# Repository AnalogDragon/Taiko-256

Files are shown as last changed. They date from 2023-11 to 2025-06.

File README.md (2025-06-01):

# Taiko-256  
Taiko JVS for Namco System 256 (246)  

Previously, running Taiko on Namco System 256 required many accessories, such as a JVS (MINI-JV PCB), a SIF PCB, and an intermediate FUTA PCB, making the setup overly complex.  
This project's PCB can fully replace the three boards mentioned above. It features two independent Taiko interfaces, an onboard Service button, and supports direct power supply via ATX.  
Alternatively, this PCB can also be used to replace only the SIF PCB and FUTA PCB while still using the original MINI-JV PCB. However, this does not provide a better experience.  

## PCB:  

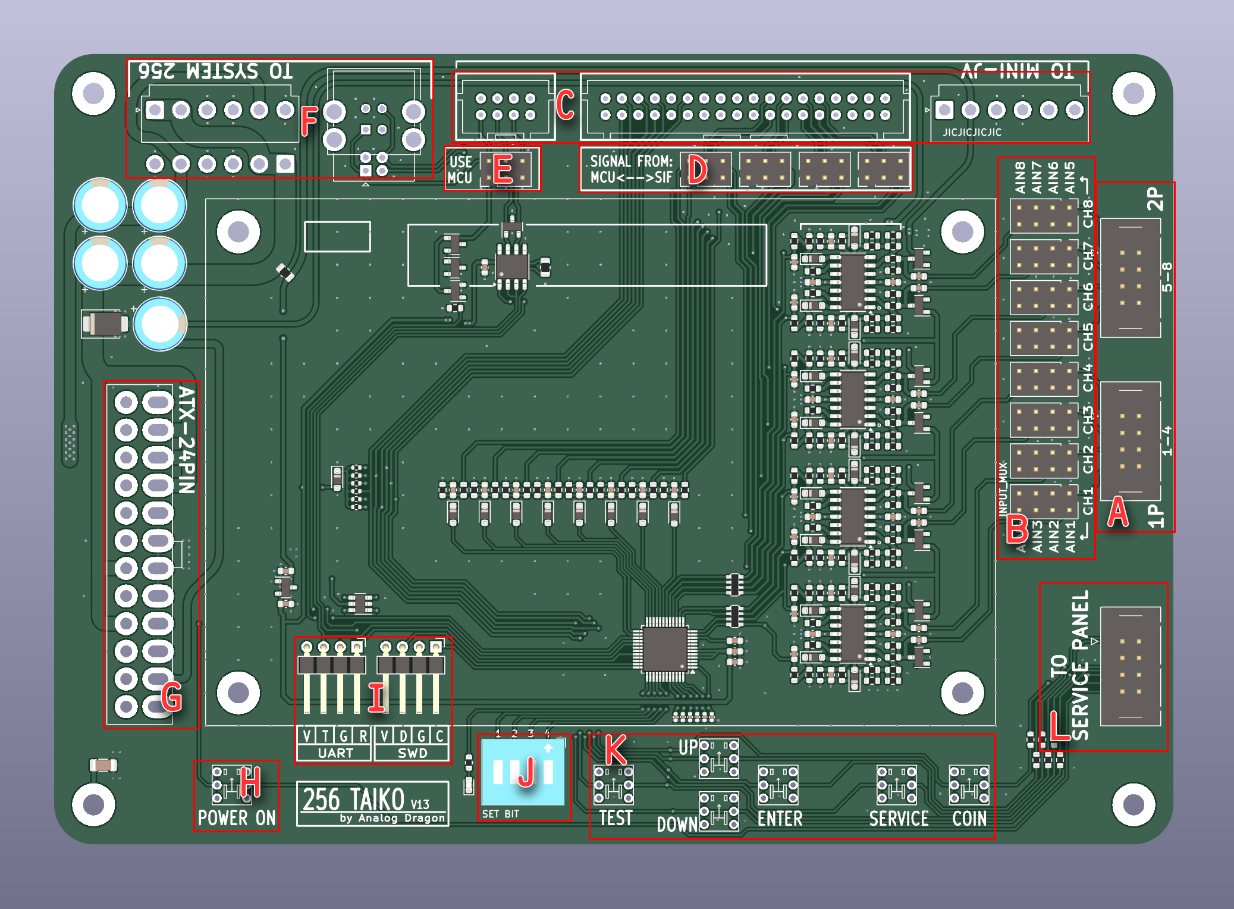
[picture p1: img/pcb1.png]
PCB
  

**Labels in the image:**  
- **A**: Taiko sensor interface. Channels 1\~4 are for Player 1, and channels 5\~8 are for Player 2. Requires connection to a Taiko with vibration sensors (the pins near the board edge are for grounding).  
- **B**: Taiko sensor input swap matrix. Jumpers can be placed in different positions to map inputs to any channel.  
- **C**: Interface for connecting to MINI-JV (can be left unconnected).  
- **D**: When connecting to MINI-JV, determines whether drum signals come from the MCU or SIF (can be left unconnected).  
- **E**: Requires three jumpers to be vertically shorted. If MINI-JV is connected, remove all three jumpers.  
- **F**: Interface for connecting to System 256. Either vertical or right-angle connectors can be soldered (ensure correct placement). For data communication, a USB-A to USB-B cable is required. For System 256 power, a VH3.96-6Pin double-ended reverse cable is needed.  
- **G**: ATX power connector. Either vertical or right-angle connectors can be soldered.  
- **H**: Power switch (requires a latching switch). Press to activate the ATX power supply.  
- **I**: Used for debug.  
- **J**: Configuration code (from left to right, digits 1~4):  
  - **1**: Debug switch (set to OFF during use).  
  - **2**: Frequency limiter switch (set to ON during use, as the System cannot handle overly fast inputs).  
  - **3**: Automatic DON allocation (if the left DON is hit multiple times, System 256 may fail to recognize excessive inputs. Allocating it to the right channel improves the experience. Recommended: ON).  
  - **4**: JVS function (set to ON. Set to OFF if connecting to MINI-JV).  
- **K**: Service function buttons. TEST requires a latching switch, while the others require momentary switches.  
- **L**: Connector for linking to a Service control panel. If the Service buttons need to be extended to another panel, this connector can be used.  

### PCB Image:  
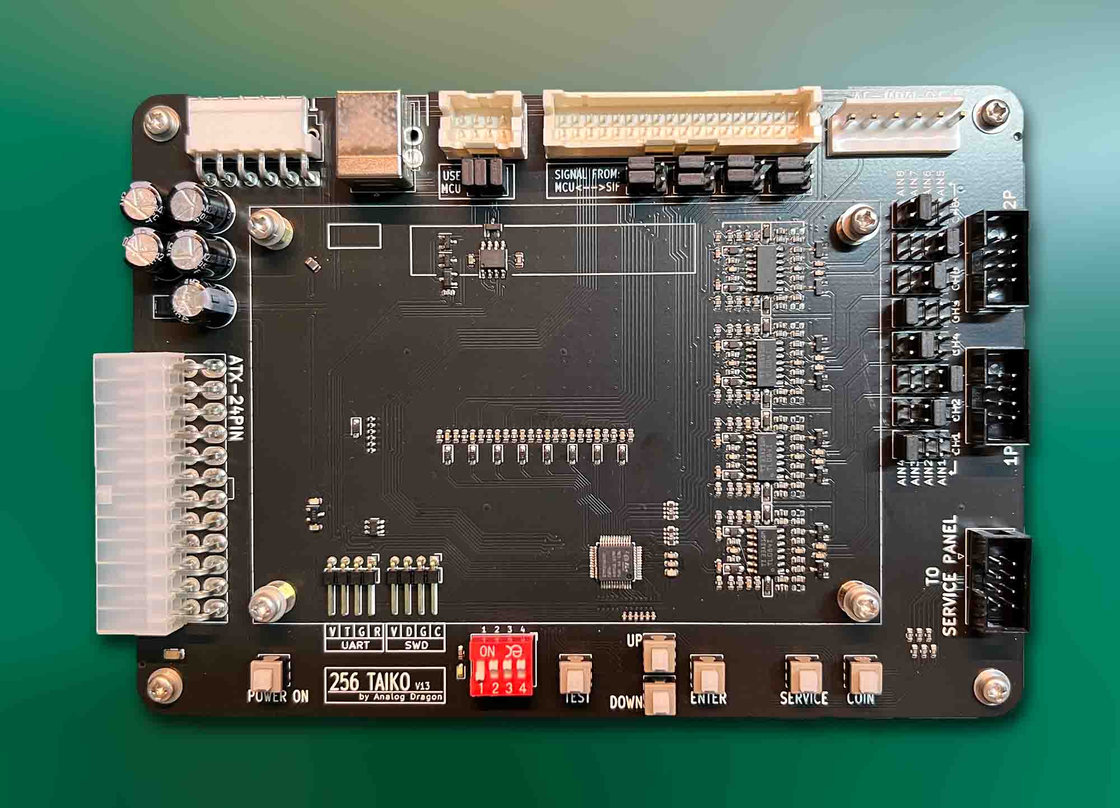
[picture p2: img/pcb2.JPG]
PCB-Photo
  
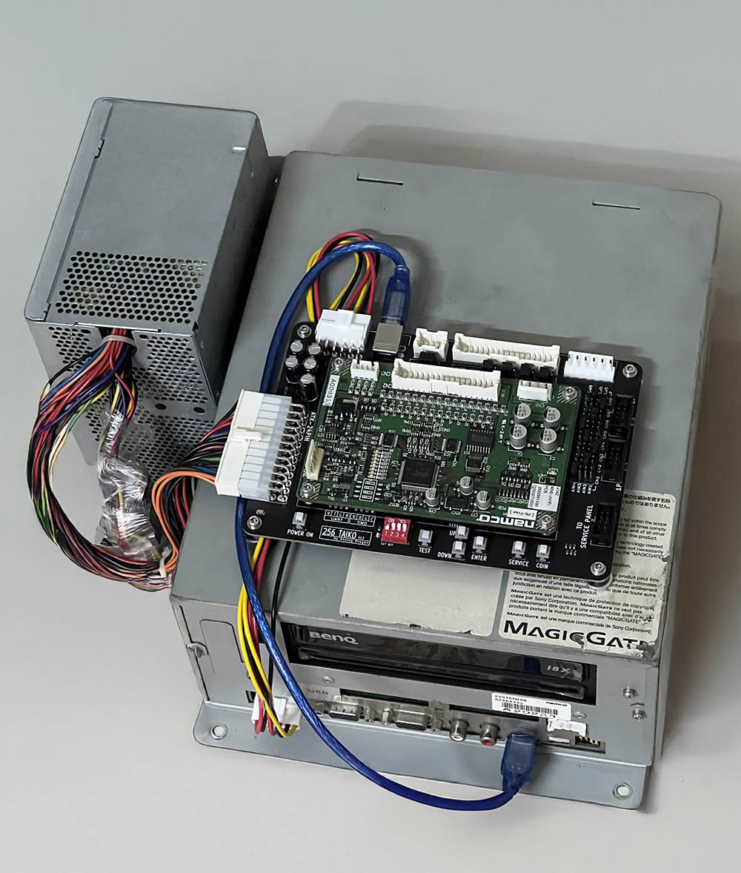
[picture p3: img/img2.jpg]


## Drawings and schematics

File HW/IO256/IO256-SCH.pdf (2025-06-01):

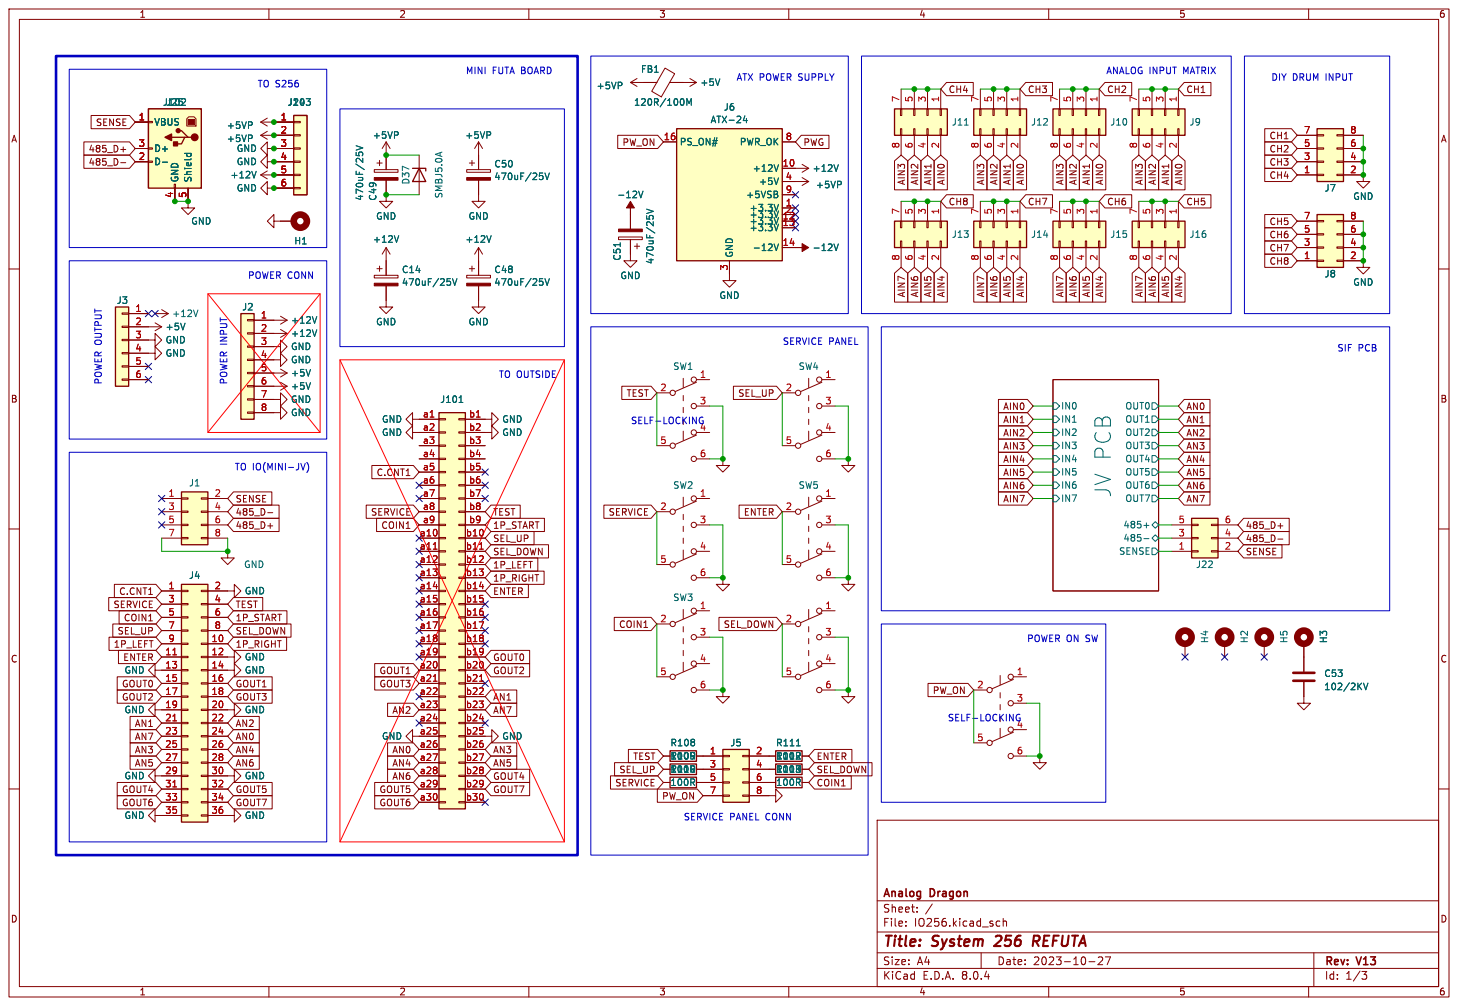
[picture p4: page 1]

ATX POWER SUPPLY POWER OUTPUT

Id: 1/3 Title: System 256 REFUTA

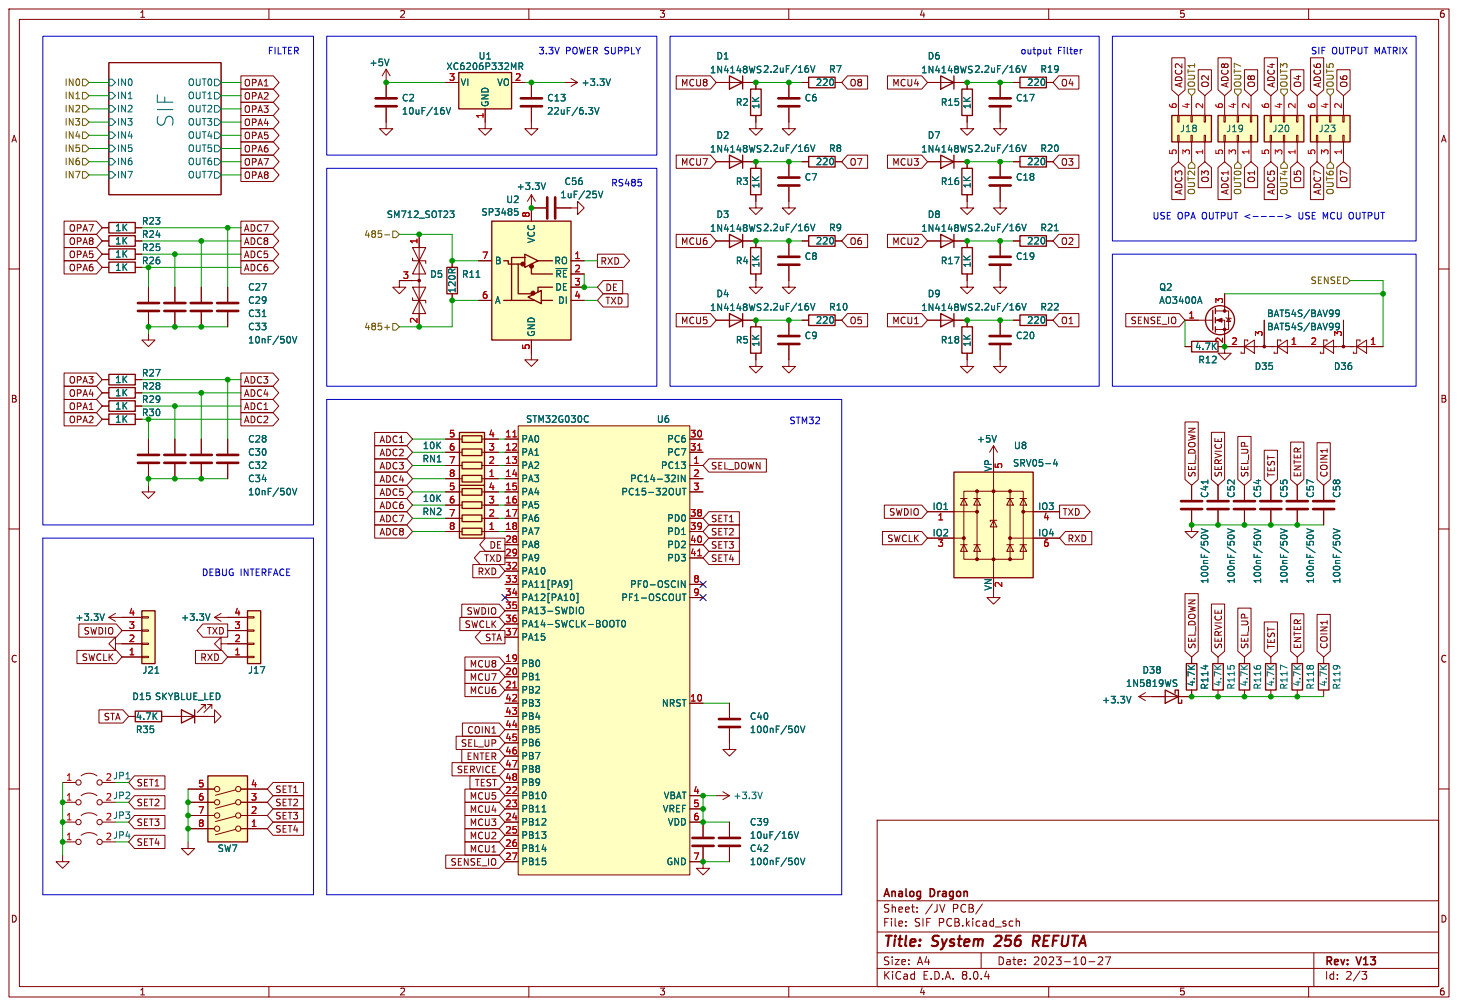
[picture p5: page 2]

Id: 2/3 Title: System 256 REFUTA

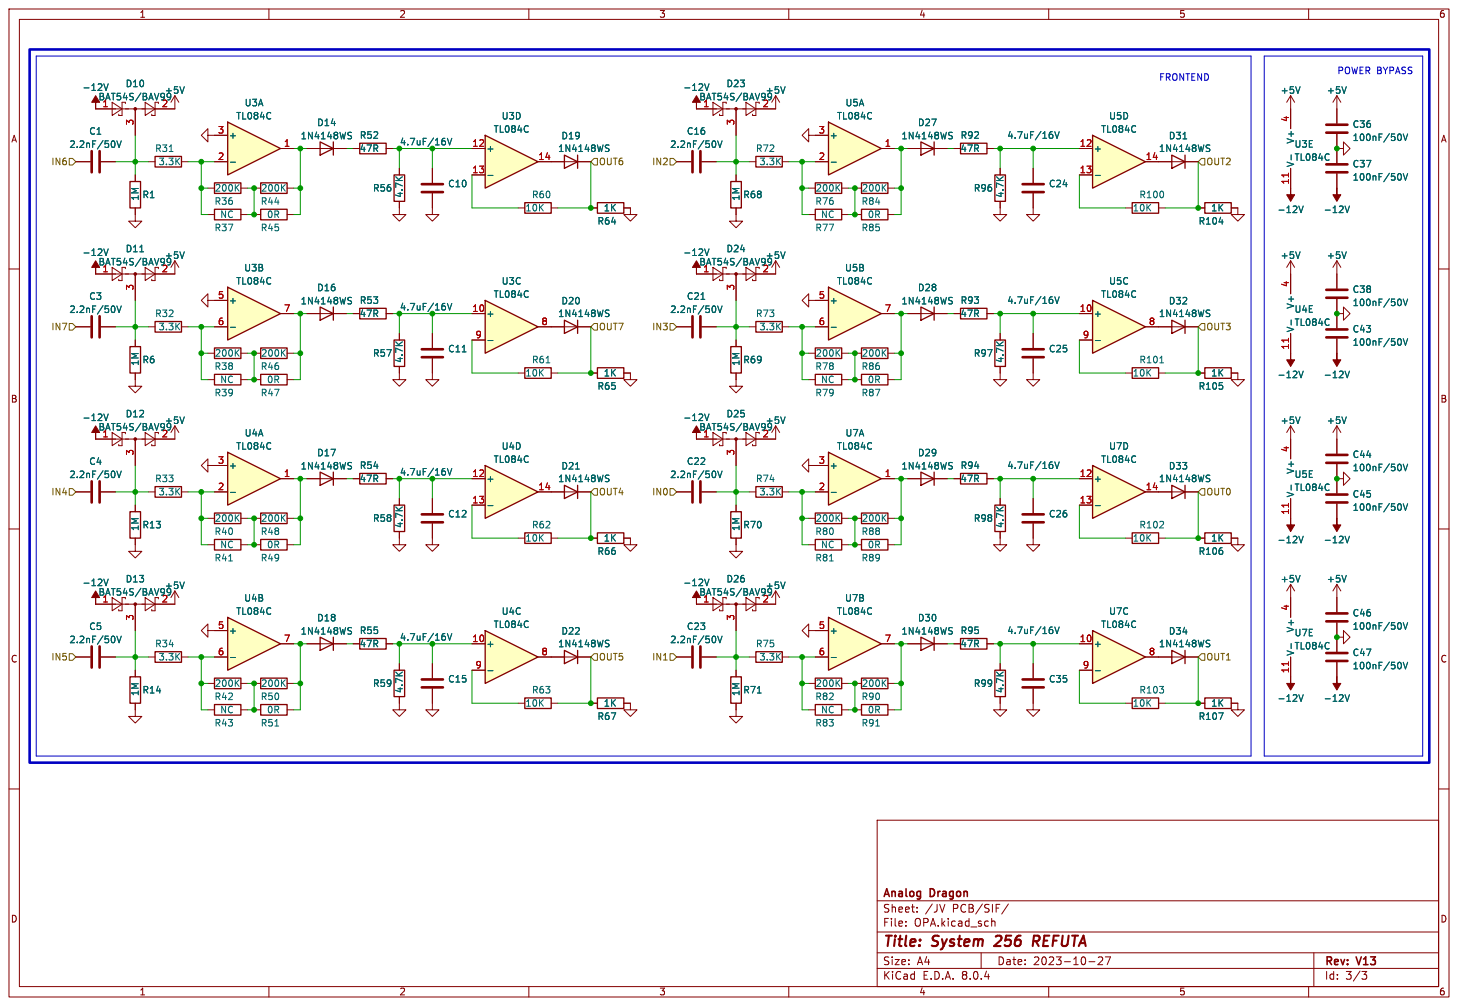
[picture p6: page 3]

Id: 3/3 Title: System 256 REFUTA

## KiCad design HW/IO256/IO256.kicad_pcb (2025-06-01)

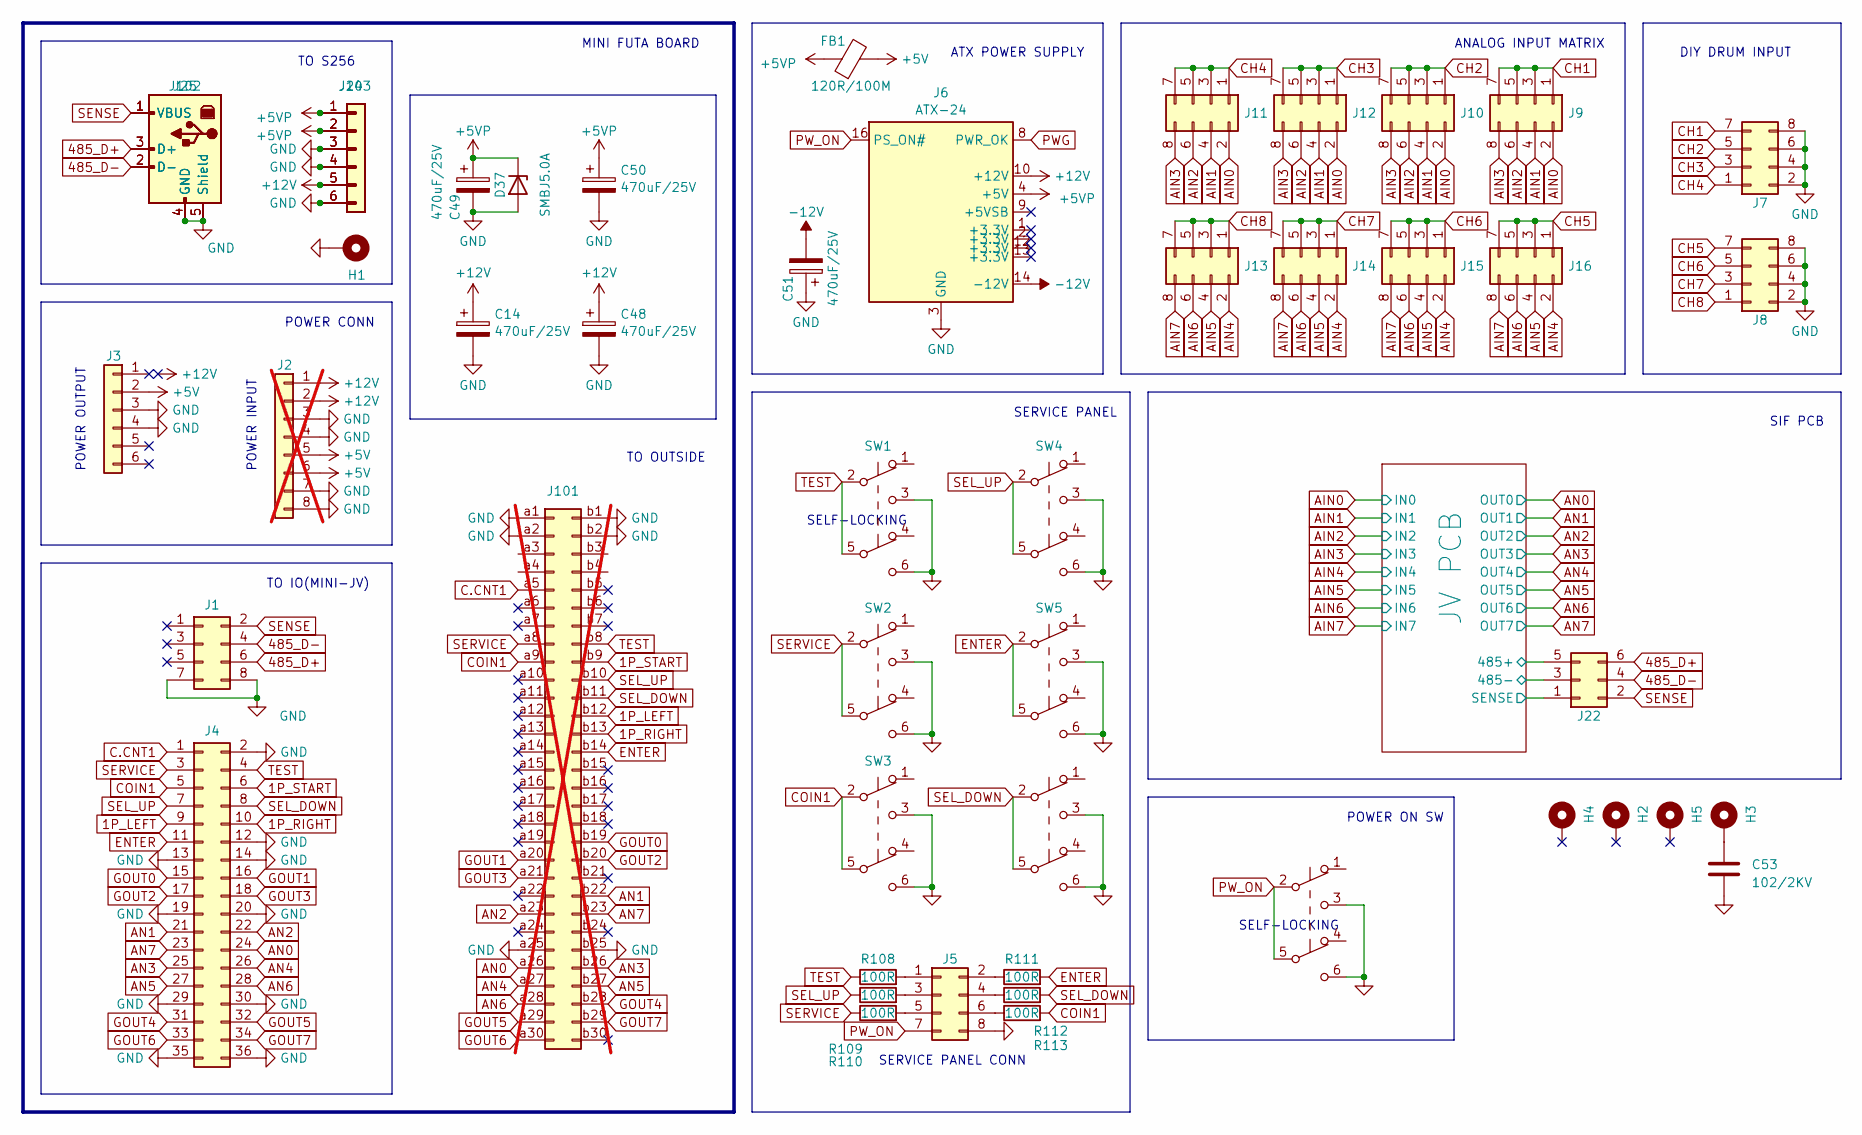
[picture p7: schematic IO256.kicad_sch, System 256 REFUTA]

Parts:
C14, C48, C49, C50, C51: 470uF/25V; CP_Radial_D8.0mm_P3.50mm
C53: 102/2KV; C_1206_3216Metric
D37: SMBJ5.0A; D_SMB
FB1: 120R/100M; R_0805_2012Metric
H1, H2, H3, H4, H5: MINI-JV; MountingHole_3.2mm_M3_DIN965_Pad
J1: Conn_02x04_Odd_Even; B08B-XADSS-N-A
J2: Conn_01x08; JST_VH_B8P-VH-B_1x08_P3.96mm_Vertical; not fitted
J3, J103: Conn_01x06; JST_VH_B6P-VH_1x06_P3.96mm_Vertical
J4: Conn_02x18_Odd_Even; B36B-XADSS-N-A
J5, J7, J8: Conn_02x04_Counter_Clockwise; IDC-Header_2x04_P2.54mm_Vertical
J6: ATX-24; 5557-2x12
J9, J10, J11, J12, J13, J14, J15, J16: Conn_02x04_Counter_Clockwise; PinHeader_2x04_P2.54mm_Vertical
J22: Conn_02x02_Odd_Even; PinHeader_2x03_P2.54mm_Vertical
J24: Conn_01x06; JST_VH_B6PS-VH_1x06_P3.96mm_Horizontal
J25: USB_B; USB_B_OST_USB-B1HSxx_Horizontal
J101: Conn_02x30_Row_Letter_First; IDC-Header_2x30_P2.54mm_Latch6.5mm_Vertical; not fitted
J102: USB_B; USB_B_TE_5787834_Vertical
R108, R109, R110, R111, R112, R113: 100R; R_0603_1608Metric
SW1, SW8: SW6*6_selflock; switch_6x6
SW2, SW3, SW4, SW5, SW6: SW6*6_button; switch_6x6

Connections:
1P_LEFT: J4.9, J101.b12
1P_RIGHT: J4.10, J101.b13
1P_START: J4.6, J101.b9
485_D+: J1.6, J22.6, J25.3 (D+), J102.3 (D+)
485_D-: J1.4, J22.4, J25.2 (D-), J102.2 (D-)
+5V: FB1.2, J2.5, J2.6, J3.2; also elsewhere on the board
+5VP: C49.1, C50.1, D37.1 (K), FB1.1, J6.4 (+5V), J6.6 (+5V), J6.21 (+5V), J6.22 (+5V), J6.23 (+5V), J24.1, J24.2, J103.1, J103.2
+12V: C14.1, C48.1, J2.1, J2.2, J6.10 (+12V), J6.11 (+12V), J24.5, J103.5
-12V: C51.2, J6.14 (-12V); also elsewhere on the board
/JV PCB/485+: J22.5; also elsewhere on the board
/JV PCB/485-: J22.3; also elsewhere on the board
/JV PCB/SENSE: J22.1; also elsewhere on the board
AIN0: J9.2, J10.2, J11.2, J12.2; also elsewhere on the board
AIN1: J9.4, J10.4, J11.4, J12.4; also elsewhere on the board
AIN2: J9.6, J10.6, J11.6, J12.6; also elsewhere on the board
AIN3: J9.8, J10.8, J11.8, J12.8; also elsewhere on the board
AIN4: J13.2, J14.2, J15.2, J16.2; also elsewhere on the board
AIN5: J13.4, J14.4, J15.4, J16.4; also elsewhere on the board
AIN6: J13.6, J14.6, J15.6, J16.6; also elsewhere on the board
AIN7: J13.8, J14.8, J15.8, J16.8; also elsewhere on the board
AN0: J4.24, J101.a26; also elsewhere on the board
AN1: J4.21, J101.b22; also elsewhere on the board
AN2: J4.22, J101.a23; also elsewhere on the board
AN3: J4.25, J101.b26; also elsewhere on the board
AN4: J4.26, J101.a27; also elsewhere on the board
AN5: J4.27, J101.b27; also elsewhere on the board
AN6: J4.28, J101.a28; also elsewhere on the board
AN7: J4.23, J101.b23; also elsewhere on the board
C.CNT1: J4.1, J101.a5
CH1: J7.7, J9.1, J9.3, J9.5, J9.7
CH2: J7.5, J10.1, J10.3, J10.5, J10.7
CH3: J7.3, J12.1, J12.3, J12.5, J12.7
CH4: J7.1, J11.1, J11.3, J11.5, J11.7
CH5: J8.7, J16.1, J16.3, J16.5, J16.7
CH6: J8.5, J15.1, J15.3, J15.5, J15.7
CH7: J8.3, J14.1, J14.3, J14.5, J14.7
CH8: J8.1, J13.1, J13.3, J13.5, J13.7
COIN1: J4.5, R113.2, SW3.2 (B), SW3.5 (B); also elsewhere on the board
ENTER: J4.11, R111.2, SW5.2 (B), SW5.5 (B); also elsewhere on the board
GND: C14.2, C48.2, C49.2, C50.2, C51.1, C53.2, D37.2 (A), H1.1, J1.7, J1.8, J2.3, J2.4, J2.7, J2.8, J3.3, J3.4, J4.2, J4.12, J4.13, J4.14, J4.19, J4.20, J4.29, J4.30, J4.35, J4.36, J5.8, J6.3 (GND), J6.5 (GND), J6.7 (GND), J6.15 (GND), J6.17 (GND), J6.18 (GND), J6.19 (GND), J6.24 (GND), J7.2, J7.4, J7.6, J7.8, J8.2, J8.4, J8.6, J8.8, J24.3, J24.4, J24.6, J25.4 (GND), J25.5 (Shield), J101.a1, J101.a2, J101.a25, J101.b1, J101.b2, J101.b25, J102.4 (GND), J102.5 (Shield), J103.3, J103.4, J103.6, SW1.3 (C), SW1.6 (C), SW2.3 (C), SW2.6 (C), SW3.3 (C), SW3.6 (C), SW4.3 (C), SW4.6 (C), SW5.3 (C), SW5.6 (C), SW6.3 (C), SW6.6 (C), SW8.3 (C), SW8.6 (C); also elsewhere on the board
GOUT0: J4.15, J101.b19
GOUT1: J4.16, J101.a20
GOUT2: J4.17, J101.b20
GOUT3: J4.18, J101.a21
GOUT4: J4.31, J101.b28
GOUT5: J4.32, J101.a29
GOUT6: J4.33, J101.a30
GOUT7: J4.34, J101.b29
unnamed: C53.1, H3.1
unnamed: J5.1, R108.2
unnamed: J5.2, R111.1
unnamed: J5.3, R109.2
unnamed: J5.4, R112.1
unnamed: J5.5, R110.2
unnamed: J5.6, R113.1
PWG: J6.8 (PWR_OK)
PW_ON: J5.7, J6.16 (PS_ON#), SW8.2 (B), SW8.5 (B)
SEL_DOWN: J4.8, R112.2, SW6.2 (B), SW6.5 (B); also elsewhere on the board
SEL_UP: J4.7, R109.1, SW4.2 (B), SW4.5 (B); also elsewhere on the board
SENSE: J1.2, J22.2, J25.1 (VBUS), J102.1 (VBUS)
SERVICE: J4.3, R110.1, SW2.2 (B), SW2.5 (B); also elsewhere on the board
TEST: J4.4, R108.1, SW1.2 (B), SW1.5 (B); also elsewhere on the board

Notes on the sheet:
SERVICE PANEL CONN
DIY DRUM INPUT
SERVICE PANEL
ANALOG INPUT MATRIX
SELF-LOCKING
TO S256
SIF PCB
MINI FUTA BOARD
POWER OUTPUT
TO OUTSIDE
TO IO(MINI-JV)
POWER CONN
ATX POWER SUPPLY
POWER INPUT
POWER ON SW

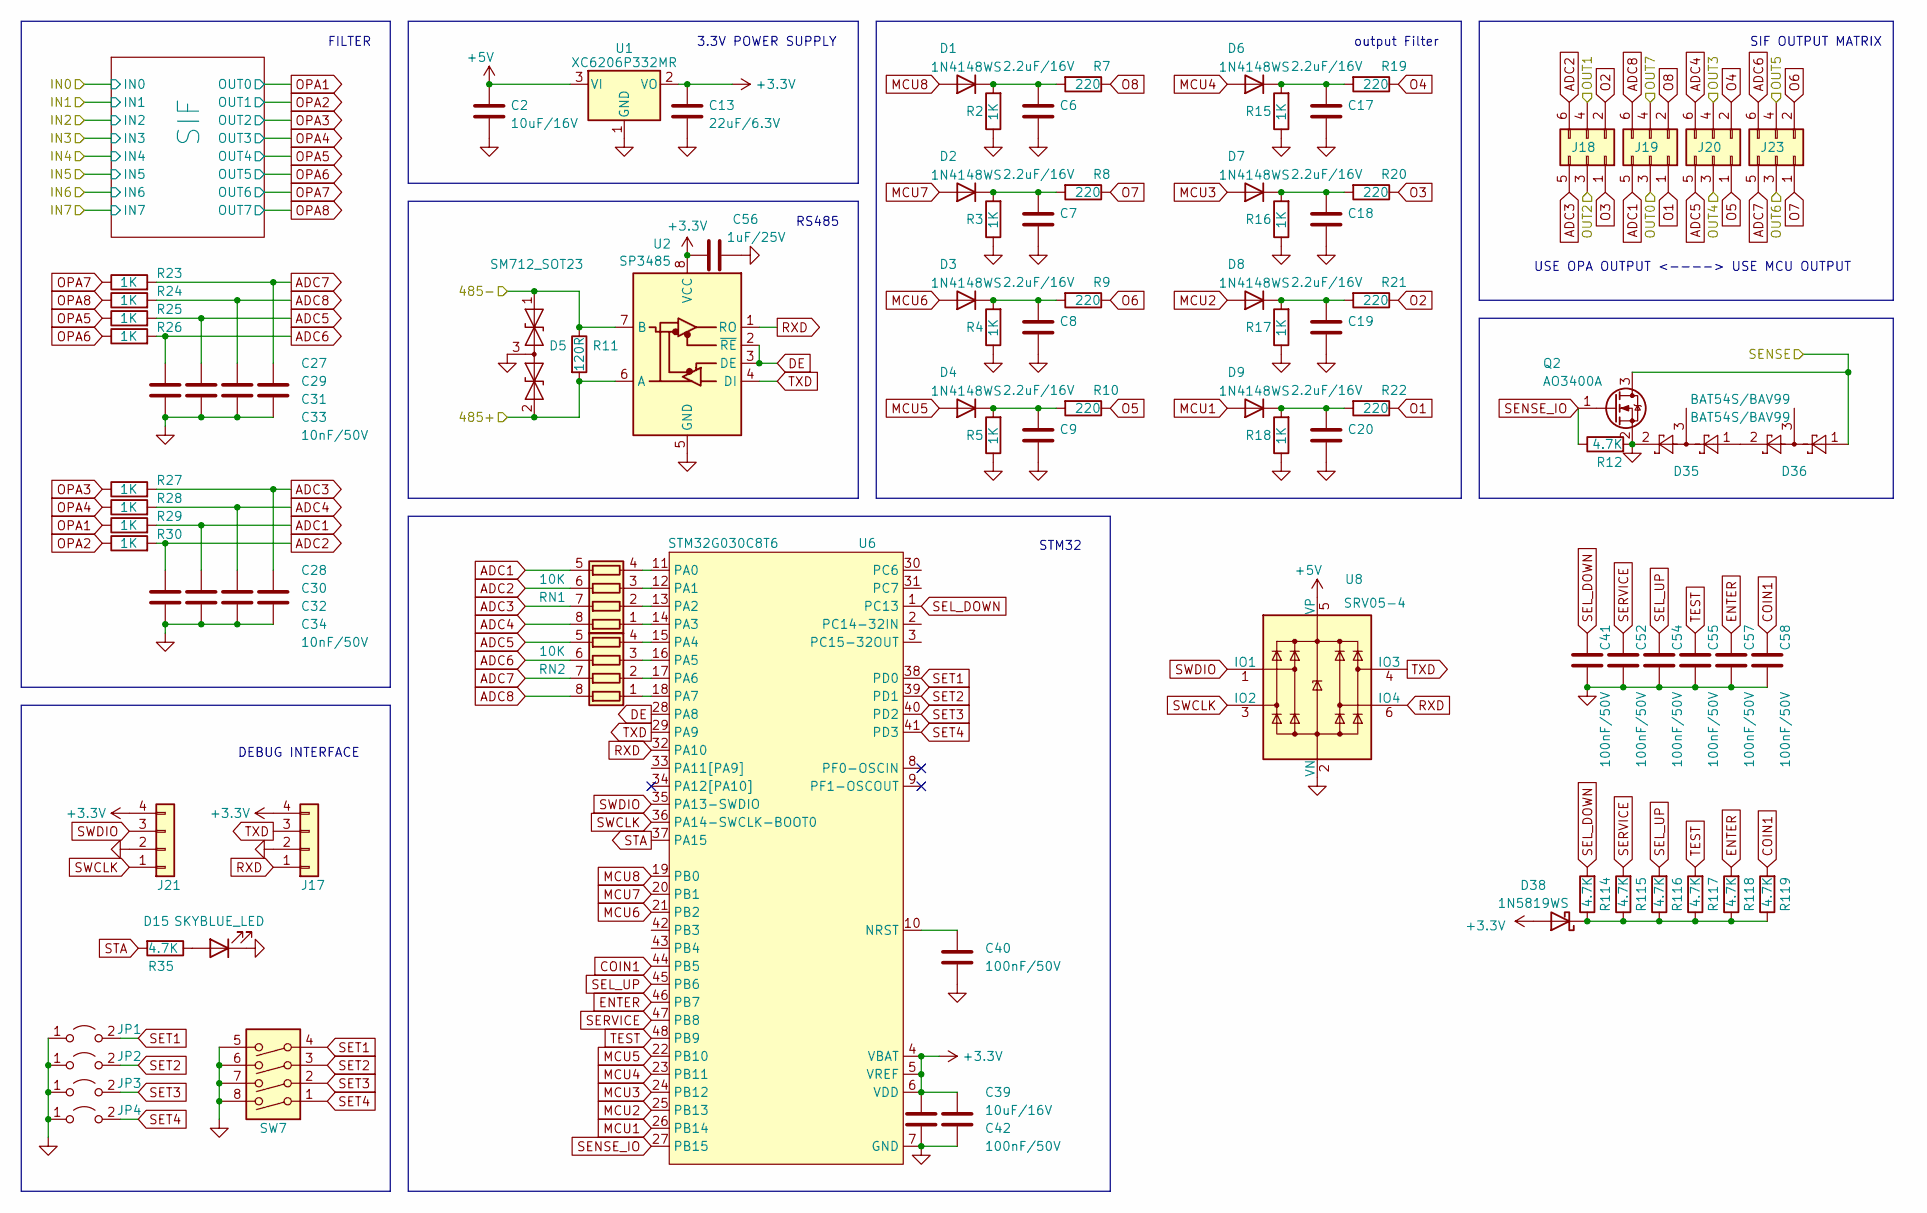
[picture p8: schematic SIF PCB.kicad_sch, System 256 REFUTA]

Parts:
C2, C39: 10uF/16V; C_0603_1608Metric
C6, C7, C8, C9, C17, C18, C19, C20: 2.2uF/16V; C_0603_1608Metric
C13: 22uF/6.3V; C_0603_1608Metric
C27, C28, C29, C30, C31, C32, C33, C34: 10nF/50V; C_0603_1608Metric
C40, C42: 100nF/50V; C_0603_1608Metric
C41, C52, C54, C55, C57, C58: 100nF/50V; C_0402_1005Metric
C56: 1uF/25V; C_0603_1608Metric
D1, D2, D3, D4, D6, D7, D8, D9: 1N4148WS; D_SOD-323_HandSoldering
D5: SM712_SOT23; SOT-23
D15: SKYBLUE_LED; LED_0603_1608Metric
D35, D36: BAT54S/BAV99; SOT-23
D38: 1N5819WS; D_SOD-323_HandSoldering
J17, J21: Conn_01x04; PinHeader_1x04_P2.54mm_Horizontal
J18, J19, J20, J23: Conn_02x03_Odd_Even; PinHeader_2x03_P2.54mm_Vertical
JP1, JP2, JP3, JP4: Jumper_2_Open; JP_0603
Q2: AO3400A; SOT-23
R2, R3, R4, R5, R15, R16, R17, R18, R23, R24, R25, R26, R27, R28, R29, R30: 1K; R_0603_1608Metric
R7, R8, R9, R10, R19, R20, R21, R22: 220; R_0603_1608Metric
R11: 120R; R_0805_2012Metric
R12, R35: 4.7K; R_0603_1608Metric
R114, R115, R116, R117, R118, R119: 4.7K; R_0402_1005Metric
RN1, RN2: 10K; R_Array_Convex_4x0603
SW7: SW_DIP_x04; SW_DIP_SPSTx04_Slide_9.78x12.34mm_W7.62mm_P2.54mm
U1: XC6206P332MR; SOT-23
U2: SP3485; SOIC-8_3.9x4.9mm_P1.27mm
U6: STM32G030C8T6; LQFP-48_7x7mm_P0.5mm
U8: SRV05-4; SOT-23-6

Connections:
+3.3V: C13.1, C39.1, C42.1, C56.1, D38.2 (A), J17.4, J21.4, U1.2 (VO), U2.8 (VCC), U6.4 (VBAT), U6.5 (VREF), U6.6 (VDD)
+5V: C2.1, U1.3 (VI), U8.5 (VP); also elsewhere on the board
/JV PCB/485+: D5.2 (A2), R11.2, U2.6 (A); also elsewhere on the board
/JV PCB/485-: D5.1 (A1), R11.1, U2.7 (B); also elsewhere on the board
/JV PCB/SENSE: D36.1, Q2.3 (D); also elsewhere on the board
ADC1: C30.1, J19.5, R29.2, RN1.5 (R4.2)
ADC2: C28.1, J18.6, R30.2, RN1.6 (R3.2)
ADC3: C34.1, J18.5, R27.2, RN1.7 (R2.2)
ADC4: C32.1, J20.6, R28.2, RN1.8 (R1.2)
ADC5: C29.1, J20.5, R25.2, RN2.5 (R4.2)
ADC6: C27.1, J23.6, R26.2, RN2.6 (R3.2)
ADC7: C33.1, J23.5, R23.2, RN2.7 (R2.2)
ADC8: C31.1, J19.6, R24.2, RN2.8 (R1.2)
AN0: J19.3; also elsewhere on the board
AN1: J18.4; also elsewhere on the board
AN2: J18.3; also elsewhere on the board
AN3: J20.4; also elsewhere on the board
AN4: J20.3; also elsewhere on the board
AN5: J23.4; also elsewhere on the board
AN6: J23.3; also elsewhere on the board
AN7: J19.4; also elsewhere on the board
COIN1: C58.1, R119.2, U6.44 (PB5); also elsewhere on the board
DE: U2.2 (~RE), U2.3 (DE), U6.28 (PA8)
ENTER: C57.1, R118.2, U6.46 (PB7); also elsewhere on the board
GND: C2.2, C6.1, C7.1, C8.1, C9.1, C13.2, C17.1, C18.1, C19.1, C20.1, C27.2, C28.2, C29.2, C30.2, C31.2, C32.2, C33.2, C34.2, C39.2, C40.2, C41.2, C42.2, C52.2, C54.2, C55.2, C56.2, C57.2, C58.2, D5.3 (common), D15.1 (K), D35.2, J17.2, J21.2, JP1.1 (A), JP2.1 (A), JP3.1 (A), JP4.1 (A), Q2.2 (S), R2.1, R3.1, R4.1, R5.1, R12.2, R15.1, R16.1, R17.1, R18.1, SW7.5, SW7.6, SW7.7, SW7.8, U1.1 (GND), U2.5 (GND), U6.7 (GND), U8.2 (VN); also elsewhere on the board
MCU1: D9.2 (A), U6.26 (PB14)
MCU2: D8.2 (A), U6.25 (PB13)
MCU3: D7.2 (A), U6.24 (PB12)
MCU4: D6.2 (A), U6.23 (PB11)
MCU5: D4.2 (A), U6.22 (PB10)
MCU6: D3.2 (A), U6.21 (PB2)
MCU7: D2.2 (A), U6.20 (PB1)
MCU8: D1.2 (A), U6.19 (PB0)
unnamed: C6.2, D1.1 (K), R2.2, R7.2
unnamed: C7.2, D2.1 (K), R3.2, R8.2
unnamed: C8.2, D3.1 (K), R4.2, R9.2
unnamed: C9.2, D4.1 (K), R5.2, R10.2
unnamed: C17.2, D6.1 (K), R15.2, R19.2
unnamed: C18.2, D7.1 (K), R16.2, R20.2
unnamed: C19.2, D8.1 (K), R17.2, R21.2
unnamed: C20.2, D9.1 (K), R18.2, R22.2
unnamed: D15.2 (A), R35.1
unnamed: D35.1, D36.2
unnamed: D38.1 (K), R114.1, R115.1, R116.1, R117.1, R118.1, R119.1
unnamed: RN1.1 (R1.1), U6.14 (PA3)
unnamed: RN1.2 (R2.1), U6.13 (PA2)
unnamed: RN1.3 (R3.1), U6.12 (PA1)
unnamed: RN1.4 (R4.1), U6.11 (PA0)
unnamed: RN2.1 (R1.1), U6.18 (PA7)
unnamed: RN2.2 (R2.1), U6.17 (PA6)
unnamed: RN2.3 (R3.1), U6.16 (PA5)
unnamed: RN2.4 (R4.1), U6.15 (PA4)
unnamed: C40.1, U6.10 (NRST)
O1: J19.1, R22.1
O2: J18.2, R21.1
O3: J18.1, R20.1
O4: J20.2, R19.1
O5: J20.1, R10.1
O6: J23.2, R9.1
O7: J23.1, R8.1
O8: J19.2, R7.1
OPA1: R29.1; also elsewhere on the board
OPA2: R30.1; also elsewhere on the board
OPA3: R27.1; also elsewhere on the board
OPA4: R28.1; also elsewhere on the board
OPA5: R25.1; also elsewhere on the board
OPA6: R26.1; also elsewhere on the board
OPA7: R23.1; also elsewhere on the board
OPA8: R24.1; also elsewhere on the board
RXD: J17.1, U2.1 (RO), U6.32 (PA10), U8.6 (IO4)
SEL_DOWN: C41.1, R114.2, U6.1 (PC13); also elsewhere on the board
SEL_UP: C54.1, R116.2, U6.45 (PB6); also elsewhere on the board
SENSE_IO: Q2.1 (G), R12.1, U6.27 (PB15)
SERVICE: C52.1, R115.2, U6.47 (PB8); also elsewhere on the board
SET1: JP1.2 (B), SW7.4, U6.38 (PD0)
SET2: JP2.2 (B), SW7.3, U6.39 (PD1)
SET3: JP3.2 (B), SW7.2, U6.40 (PD2)
SET4: JP4.2 (B), SW7.1, U6.41 (PD3)
STA: R35.2, U6.37 (PA15)
SWCLK: J21.1, U6.36 (PA14-SWCLK-BOOT0), U8.3 (IO2)
SWDIO: J21.3, U6.35 (PA13-SWDIO), U8.1 (IO1)
TEST: C55.1, R117.2, U6.48 (PB9); also elsewhere on the board
TXD: J17.3, U2.4 (DI), U6.29 (PA9), U8.4 (IO3)

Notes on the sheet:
SIF OUTPUT MATRIX
DEBUG INTERFACE
STM32
3.3V POWER SUPPLY
RS485
output Filter
USE OPA OUTPUT <----> USE MCU OUTPUT
FILTER

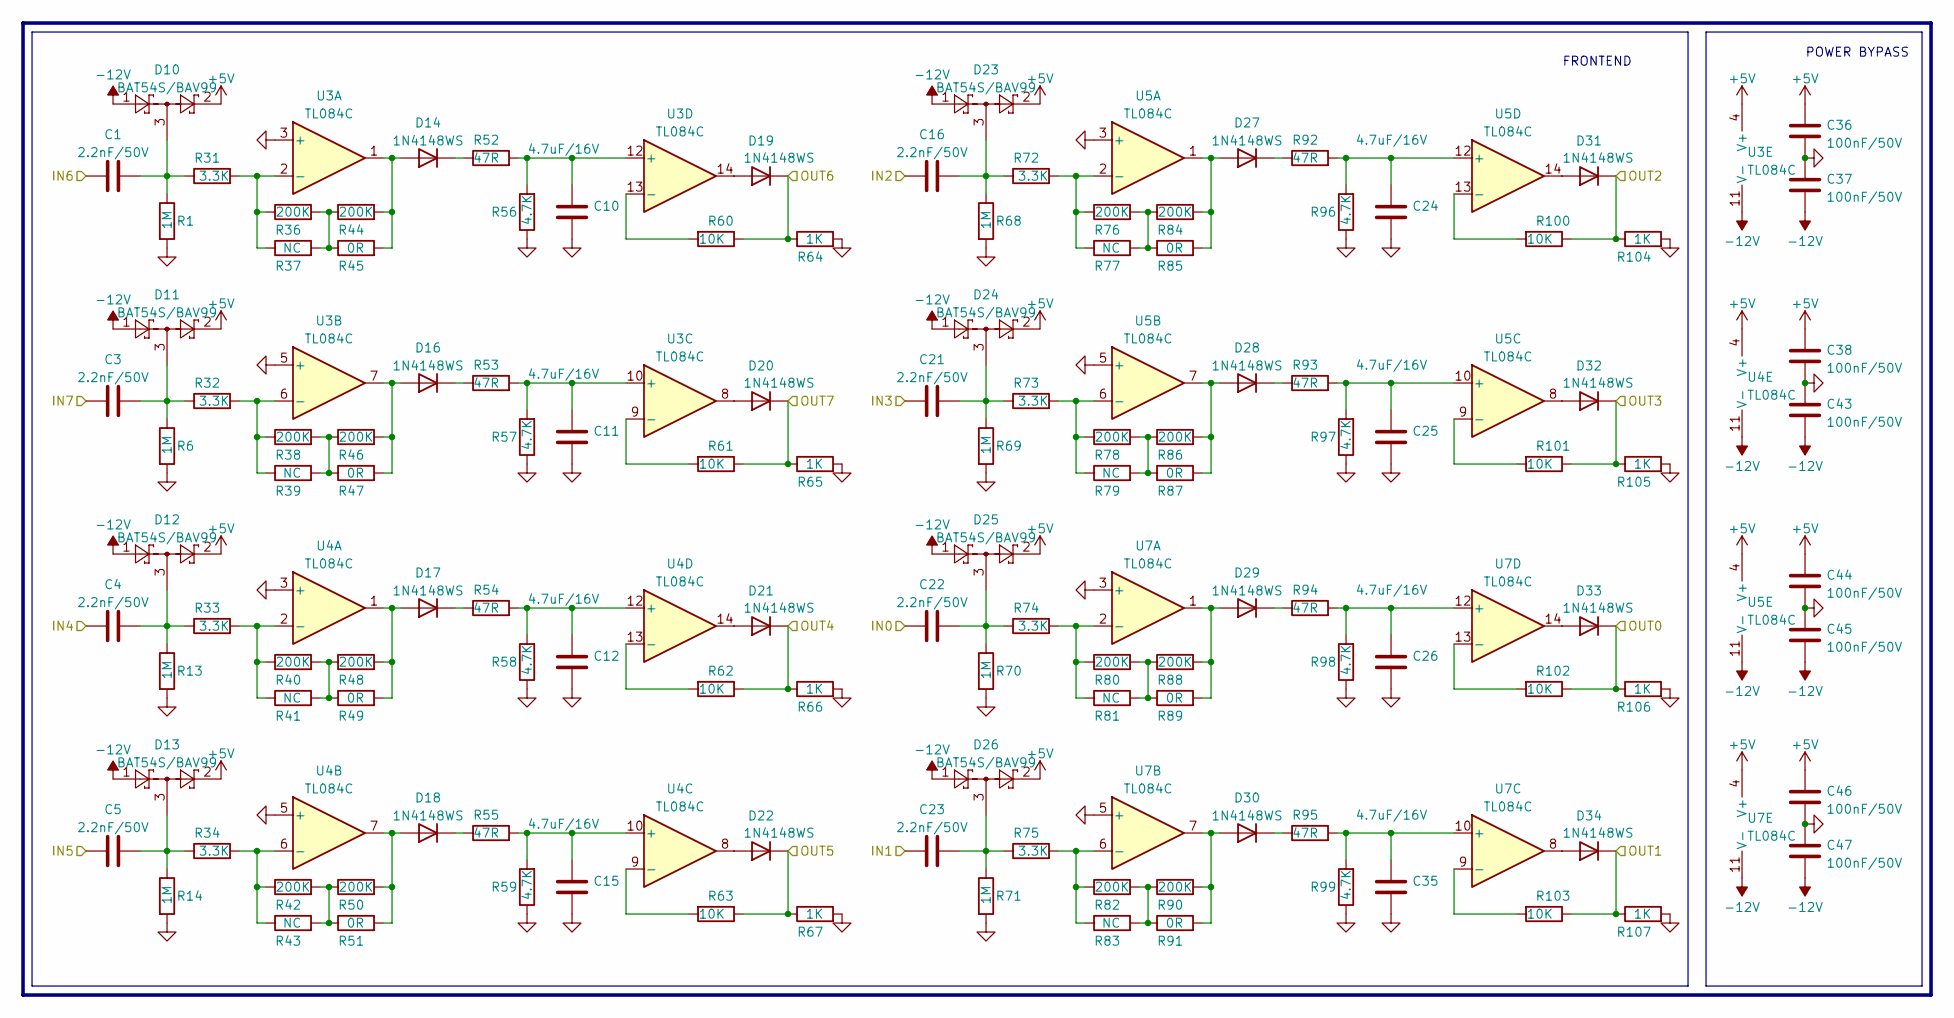
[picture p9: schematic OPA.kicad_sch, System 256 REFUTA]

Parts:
C1, C3, C4, C5, C16, C21, C22, C23: 2.2nF/50V; C_0603_1608Metric
C10, C11, C12, C15, C24, C25, C26, C35: 4.7uF/16V; C_0603_1608Metric
C36, C37, C38, C43, C44, C45, C46, C47: 100nF/50V; C_0603_1608Metric
D10, D11, D12, D13, D23, D24, D25, D26: BAT54S/BAV99; SOT-23
D14, D16, D17, D18, D19, D20, D21, D22, D27, D28, D29, D30, D31, D32, D33, D34: 1N4148WS; D_SOD-323_HandSoldering
R1, R6, R13, R14, R68, R69, R70, R71: 1M; R_0603_1608Metric
R31, R32, R33, R34, R72, R73, R74, R75: 3.3K; R_0603_1608Metric
R36, R38, R40, R42, R44, R46, R48, R50, R76, R78, R80, R82, R84, R86, R88, R90: 200K; R_0603_1608Metric
R37, R39, R41, R43, R77, R79, R81, R83: NC; R_0603_1608Metric
R45, R47, R49, R51, R85, R87, R89, R91: 0R; R_0603_1608Metric
R52, R53, R54, R55, R92, R93, R94, R95: 47R; R_0603_1608Metric
R56, R57, R58, R59, R96, R97, R98, R99: 4.7K; R_0603_1608Metric
R60, R61, R62, R63, R100, R101, R102, R103: 10K; R_0603_1608Metric
R64, R65, R66, R67, R104, R105, R106, R107: 1K; R_0603_1608Metric
U3, U4, U5, U7: TL084C; SO-14_3.9x8.65mm_P1.27mm

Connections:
+5V: C36.2, C38.2, C44.2, C46.2, D10.2, D11.2, D12.2, D13.2, D23.2, D24.2, D25.2, D26.2, U3.4 (V+), U4.4 (V+), U5.4 (V+), U7.4 (V+); also elsewhere on the board
-12V: C37.1, C43.1, C45.1, C47.1, D10.1, D11.1, D12.1, D13.1, D23.1, D24.1, D25.1, D26.1, U3.11 (V-), U4.11 (V-), U5.11 (V-), U7.11 (V-); also elsewhere on the board
AIN0: C22.1; also elsewhere on the board
AIN1: C23.1; also elsewhere on the board
AIN2: C16.1; also elsewhere on the board
AIN3: C21.1; also elsewhere on the board
AIN4: C4.1; also elsewhere on the board
AIN5: C5.1; also elsewhere on the board
AIN6: C1.1; also elsewhere on the board
AIN7: C3.1; also elsewhere on the board
GND: C10.1, C11.1, C12.1, C15.1, C24.1, C25.1, C26.1, C35.1, C36.1, C37.2, C38.1, C43.2, C44.1, C45.2, C46.1, C47.2, R1.2, R6.2, R13.2, R14.2, R56.1, R57.1, R58.1, R59.1, R64.2, R65.2, R66.2, R67.2, R68.2, R69.2, R70.2, R71.2, R96.1, R97.1, R98.1, R99.1, R104.2, R105.2, R106.2, R107.2, U3.3 (+), U3.5 (+), U4.3 (+), U4.5 (+), U5.3 (+), U5.5 (+), U7.3 (+), U7.5 (+); also elsewhere on the board
unnamed: C1.2, D10.3, R1.1, R31.1
unnamed: C3.2, D11.3, R6.1, R32.1
unnamed: C4.2, D12.3, R13.1, R33.1
unnamed: C5.2, D13.3, R14.1, R34.1
unnamed: C16.2, D23.3, R68.1, R72.1
unnamed: C21.2, D24.3, R69.1, R73.1
unnamed: C22.2, D25.3, R70.1, R74.1
unnamed: C23.2, D26.3, R71.1, R75.1
unnamed: D14.2 (A), R44.2, R45.2, U3.1
unnamed: D14.1 (K), R52.1
unnamed: D16.2 (A), R46.2, R47.2, U3.7
unnamed: D16.1 (K), R53.1
unnamed: D17.2 (A), R48.2, R49.2, U4.1
unnamed: D17.1 (K), R54.1
unnamed: D18.2 (A), R50.2, R51.2, U4.7
unnamed: D18.1 (K), R55.1
unnamed: D19.2 (A), U3.14
unnamed: D20.2 (A), U3.8
unnamed: D21.2 (A), U4.14
unnamed: D22.2 (A), U4.8
unnamed: D27.2 (A), R84.2, R85.2, U5.1
unnamed: D27.1 (K), R92.1
unnamed: D28.2 (A), R86.2, R87.2, U5.7
unnamed: D28.1 (K), R93.1
unnamed: D29.2 (A), R88.2, R89.2, U7.1
unnamed: D29.1 (K), R94.1
unnamed: D30.2 (A), R90.2, R91.2, U7.7
unnamed: D30.1 (K), R95.1
unnamed: D31.2 (A), U5.14
unnamed: D32.2 (A), U5.8
unnamed: D33.2 (A), U7.14
unnamed: D34.2 (A), U7.8
unnamed: R36.2, R37.2, R44.1, R45.1
unnamed: R38.2, R39.2, R46.1, R47.1
unnamed: R40.2, R41.2, R48.1, R49.1
unnamed: R42.2, R43.2, R50.1, R51.1
unnamed: R76.2, R77.2, R84.1, R85.1
unnamed: R78.2, R79.2, R86.1, R87.1
unnamed: R80.2, R81.2, R88.1, R89.1
unnamed: R82.2, R83.2, R90.1, R91.1
unnamed: R31.2, R36.1, R37.1, U3.2 (-)
unnamed: R32.2, R38.1, R39.1, U3.6 (-)
unnamed: C11.2, R53.2, R57.2, U3.10 (+)
unnamed: R61.2, U3.9 (-)
unnamed: C10.2, R52.2, R56.2, U3.12 (+)
unnamed: R60.2, U3.13 (-)
unnamed: R33.2, R40.1, R41.1, U4.2 (-)
unnamed: R34.2, R42.1, R43.1, U4.6 (-)
unnamed: C15.2, R55.2, R59.2, U4.10 (+)
unnamed: R63.2, U4.9 (-)
unnamed: C12.2, R54.2, R58.2, U4.12 (+)
unnamed: R62.2, U4.13 (-)
unnamed: R72.2, R76.1, R77.1, U5.2 (-)
unnamed: R73.2, R78.1, R79.1, U5.6 (-)
unnamed: C25.2, R93.2, R97.2, U5.10 (+)
unnamed: R101.2, U5.9 (-)
unnamed: C24.2, R92.2, R96.2, U5.12 (+)
unnamed: R100.2, U5.13 (-)
unnamed: R74.2, R80.1, R81.1, U7.2 (-)
unnamed: R75.2, R82.1, R83.1, U7.6 (-)
unnamed: C35.2, R95.2, R99.2, U7.10 (+)
unnamed: R103.2, U7.9 (-)
unnamed: C26.2, R94.2, R98.2, U7.12 (+)
unnamed: R102.2, U7.13 (-)
OPA1: D33.1 (K), R102.1, R106.1; also elsewhere on the board
OPA2: D34.1 (K), R103.1, R107.1; also elsewhere on the board
OPA3: D31.1 (K), R100.1, R104.1; also elsewhere on the board
OPA4: D32.1 (K), R101.1, R105.1; also elsewhere on the board
OPA5: D21.1 (K), R62.1, R66.1; also elsewhere on the board
OPA6: D22.1 (K), R63.1, R67.1; also elsewhere on the board
OPA7: D19.1 (K), R60.1, R64.1; also elsewhere on the board
OPA8: D20.1 (K), R61.1, R65.1; also elsewhere on the board

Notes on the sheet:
POWER BYPASS
FRONTEND

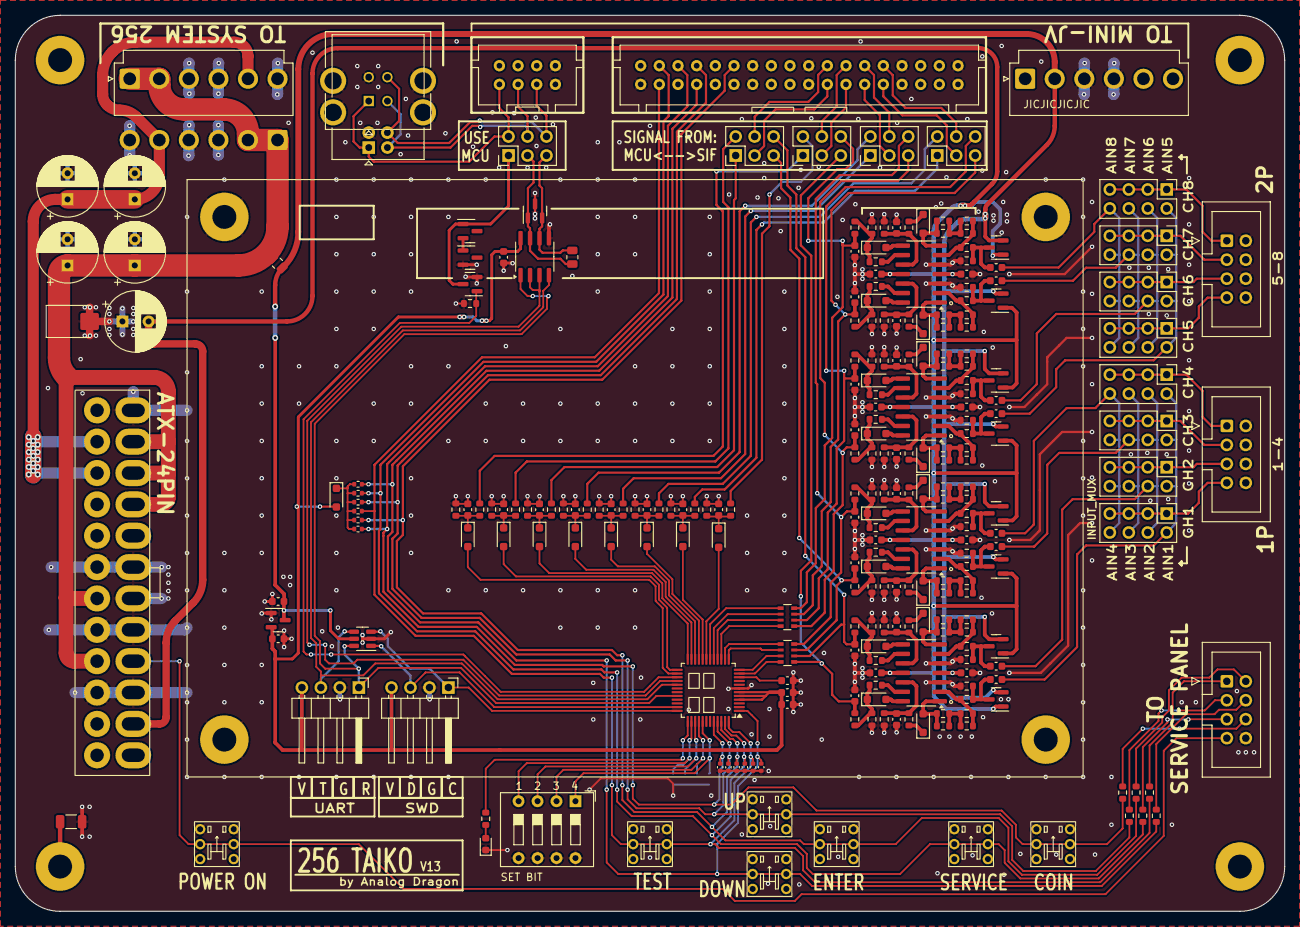
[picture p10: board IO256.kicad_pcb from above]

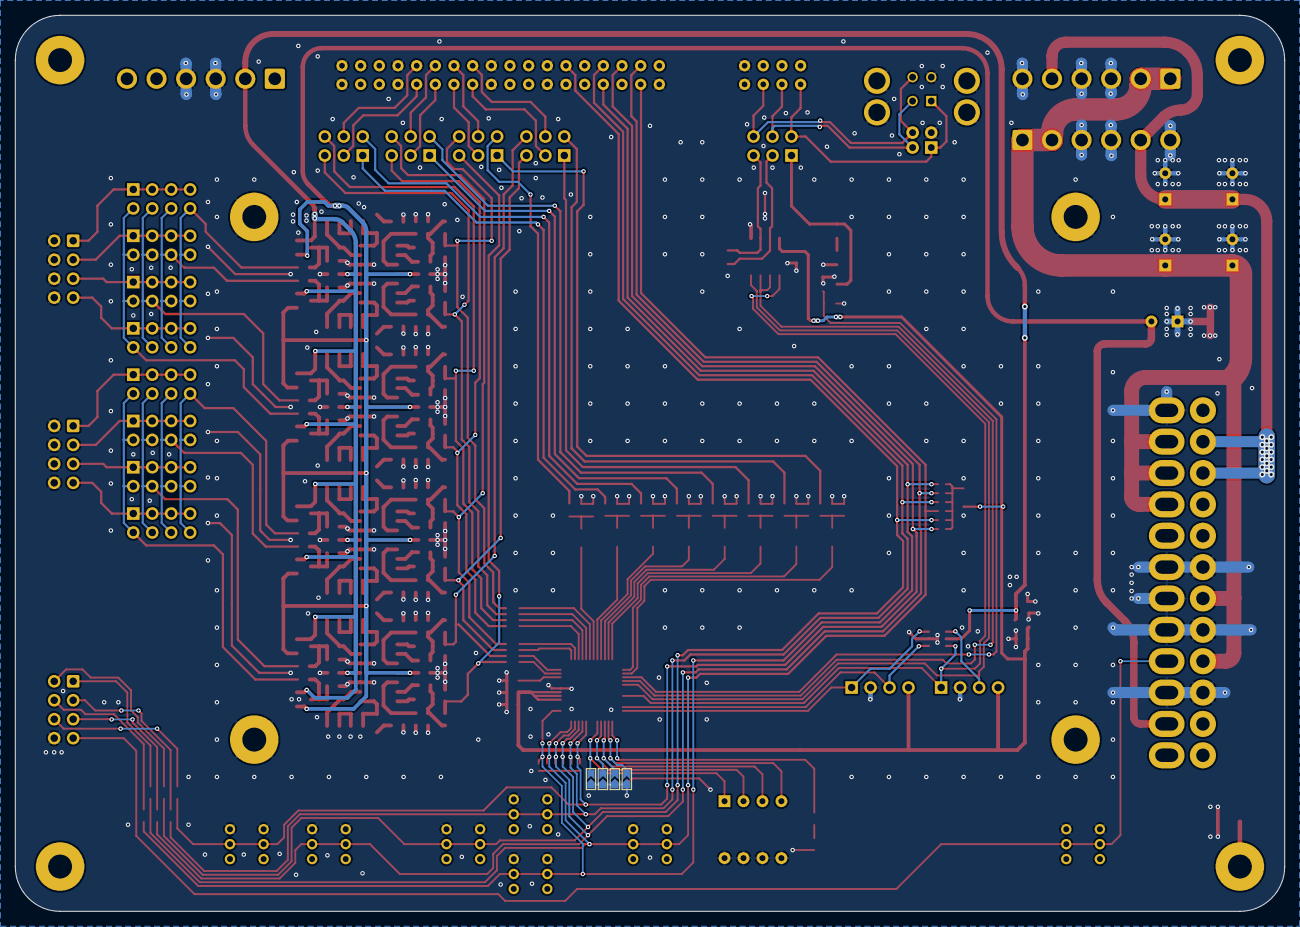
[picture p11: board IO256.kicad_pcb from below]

Board: 2 copper layers, 170.0 x 120.0 mm, 270 parts (4 on the bottom side), 177 nets.

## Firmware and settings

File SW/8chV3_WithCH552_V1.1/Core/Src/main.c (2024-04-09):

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
/* Includes ------------------------------------------------------------------*/
#include "main.h"

/* USER CODE BEGIN Includes */
#include "save.h"


/* USER CODE END Includes */

ADC_HandleTypeDef hadc1;
DMA_HandleTypeDef hdma_adc1;

IWDG_HandleTypeDef hiwdg;

TIM_HandleTypeDef htim14;

UART_HandleTypeDef huart1;
DMA_HandleTypeDef hdma_usart1_tx;

void SystemClock_Config(void);
static void MX_GPIO_Init(void);
static void MX_IWDG_Init(void);
static void MX_DMA_Init(void);
static void MX_USART1_UART_Init(void);
static void MX_TIM14_Init(void);
static void MX_ADC1_Init(void);
/* USER CODE BEGIN PFP */
static void MX_USART1_UART_Init246(void);
/* USER CODE END PFP */

/* USER CODE BEGIN 0 */


uint8_t OUT_BUFFER_LEN_D = 2;
uint8_t OUT_BUFFER_LEN_K = 2;

uint8_t with_feq_limit = 0;        //输出频率限制
uint8_t with_input_balance = 0;    //允许咚交叉输入
uint8_t this_is_12ASIA = 0;       //12亚专用

uint8_t output_count[8] = {0};  //输出缓存

uint8_t kb_lmt_count[8] = {0};  //输出冷却倒计


#define ADC_BUFFER_SIZE     10
#define ADC_LIST_SIZE       6
#define ADC_CHANNEL_NUM     8
#define CHANNEL_NUM     		8

uint8_t POWER_ON_EN = 0;


uint8_t KEY_TEST = 0;
uint8_t KEY_SERVICE = 0;
uint8_t KEY_COIN = 0;
uint8_t KEY_UP_SET = 0;
uint8_t KEY_DN_SET = 0;
uint8_t KEY_ENTER = 0;
uint8_t COIN_LOCK = 0;



uint16_t P1_KL = 0;
uint16_t P1_DL = 0;
uint16_t P1_DR = 0;
uint16_t P1_KR = 0;

uint16_t P2_KL = 0;
uint16_t P2_DL = 0;
uint16_t P2_DR = 0;
uint16_t P2_KR = 0;

uint8_t UnknowCMD = 0;
uint16_t JVS_OK = 0;


//
void GPIO_Output(uint8_t IO, uint8_t state){
  switch(IO){
    case 3:if(state)OUT1_GPIO_Port->BSRR = (uint32_t)OUT1_Pin;else OUT1_GPIO_Port->BRR = (uint32_t)OUT1_Pin;break;
    case 2:if(state)OUT2_GPIO_Port->BSRR = (uint32_t)OUT2_Pin;else OUT2_GPIO_Port->BRR = (uint32_t)OUT2_Pin;break;
    case 1:if(state)OUT3_GPIO_Port->BSRR = (uint32_t)OUT3_Pin;else OUT3_GPIO_Port->BRR = (uint32_t)OUT3_Pin;break;
    case 0:if(state)OUT4_GPIO_Port->BSRR = (uint32_t)OUT4_Pin;else OUT4_GPIO_Port->BRR = (uint32_t)OUT4_Pin;break;
    case 7:if(state)OUT5_GPIO_Port->BSRR = (uint32_t)OUT5_Pin;else OUT5_GPIO_Port->BRR = (uint32_t)OUT5_Pin;break;
    case 6:if(state)OUT6_GPIO_Port->BSRR = (uint32_t)OUT6_Pin;else OUT6_GPIO_Port->BRR = (uint32_t)OUT6_Pin;break;
    case 5:if(state)OUT7_GPIO_Port->BSRR = (uint32_t)OUT7_Pin;else OUT7_GPIO_Port->BRR = (uint32_t)OUT7_Pin;break;
    case 4:if(state)OUT8_GPIO_Port->BSRR = (uint32_t)OUT8_Pin;else OUT8_GPIO_Port->BRR = (uint32_t)OUT8_Pin;break;
  }
}

volatile uint16_t I_Buffer = 0;
volatile uint16_t O_Buffer = 0;
volatile uint16_t O_CountDown[CHANNEL_NUM] = {0};

volatile uint16_t ADC_Buffer[ADC_BUFFER_SIZE][ADC_CHANNEL_NUM];
volatile uint16_t ADC_List[ADC_CHANNEL_NUM][ADC_LIST_SIZE];
volatile uint16_t ADC_Now[ADC_CHANNEL_NUM];

volatile uint16_t ADC_Zero[ADC_CHANNEL_NUM] = {0};

volatile uint8_t InputCount[CHANNEL_NUM] = {0};
volatile uint16_t InputLevel_MAX[CHANNEL_NUM] = {0};
volatile uint16_t InputLevel_Now[CHANNEL_NUM] = {0};


uint8_t SystemError = 0;


uint8_t SET_1 = 0;
uint8_t SET_2 = 0;
uint8_t SET_3 = 0;
uint8_t SET_4 = 0;

#if (IS_S256 == 1)

#define KB_LMT_COUNT  32
#define KB_LMT_TRIG   (KB_LMT_COUNT - 10)

#else

#define KB_LMT_COUNT  32
#define KB_LMT_TRIG   (KB_LMT_COUNT - 1)

#endif

//输出函数
void IO_OutputList(void){
	static uint8_t flag[8] = {0};
	
	if(with_feq_limit){
		
		
		//老的函数用来获取敲击数
		for(uint8_t i = 0; i < CHANNEL_NUM; i ++){
			if(O_Buffer & (1 << i)){
				
				if(POWER_ON_EN){
					if(flag[i] == 0){
						flag[i] = 1;
					}
					else flag[i] = 0xFF;
				}
				
				O_CountDown[i]--;
				
				if(O_CountDown[i] == 0){
					O_Buffer &= ~(1 << i);
					I_Buffer &= ~(1 << i);
				}
			}
			else{
				O_CountDown[i] = 0;
				flag[i] = 0;
			}
		}
		
    //计数器
		if(flag[0] == 1 && output_count[0] < OUT_BUFFER_LEN_K)output_count[0]++;
		if(flag[1] == 1 && output_count[1] < OUT_BUFFER_LEN_D)output_count[1]++;
		if(flag[2] == 1 && output_count[2] < OUT_BUFFER_LEN_D)output_count[2]++;
		if(flag[3] == 1 && output_count[3] < OUT_BUFFER_LEN_K)output_count[3]++;
		if(flag[4] == 1 && output_count[4] < OUT_BUFFER_LEN_K)output_count[4]++;
		if(flag[5] == 1 && output_count[5] < OUT_BUFFER_LEN_D)output_count[5]++;
		if(flag[6] == 1 && output_count[6] < OUT_BUFFER_LEN_D)output_count[6]++;
		if(flag[7] == 1 && output_count[7] < OUT_BUFFER_LEN_K)output_count[7]++;

    //修改这个函数为960Hz，则每32个周期为30Hz
		//展开效率高一丢丢

    //1P
    //1 = LK
    if(output_count[0] && kb_lmt_count[0] == 0){
      output_count[0]--;
			P1_KL = 1023;
      kb_lmt_count[0] = KB_LMT_COUNT;
      if(kb_lmt_count[3] == 0)kb_lmt_count[3] = KB_LMT_COUNT/2;
    }
    //4 = RK
    if(output_count[3] && kb_lmt_count[3] == 0){
      output_count[3]--;
			P1_KR = 1023;
      kb_lmt_count[3] = KB_LMT_COUNT;
      if(kb_lmt_count[0] == 0)kb_lmt_count[0] = KB_LMT_COUNT/2;
    }
    //2 = LD
    if(output_count[1] && kb_lmt_count[1] == 0){
      output_count[1]--;
			P1_DL = 1023;
      kb_lmt_count[1] = KB_LMT_COUNT;
      if(kb_lmt_count[2] == 0)kb_lmt_count[2] = KB_LMT_COUNT/2;
    }
    //3 = RD
    if(output_count[2] && kb_lmt_count[2] == 0){
      output_count[2]--;
			P1_DR = 1023;
      kb_lmt_count[2] = KB_LMT_COUNT;
      if(kb_lmt_count[1] == 0)kb_lmt_count[1] = KB_LMT_COUNT/2;
    }


    //2P
    //1 = LK
    if(output_count[4] && kb_lmt_count[4] == 0){
      output_count[4]--;
			P2_KL = 1023;
      kb_lmt_count[4] = KB_LMT_COUNT;
      if(kb_lmt_count[7] == 0)kb_lmt_count[7] = KB_LMT_COUNT/2;
    }
    //4 = RK
    if(output_count[7] && kb_lmt_count[7] == 0){
      output_count[7]--;
			P2_KR = 1023;
      kb_lmt_count[7] = KB_LMT_COUNT;
      if(kb_lmt_count[4] == 0)kb_lmt_count[4] = KB_LMT_COUNT/2;
    }
    //2 = LD
    if(output_count[5] && kb_lmt_count[5] == 0){
      output_count[5]--;
			P2_DL = 1023;
      kb_lmt_count[5] = KB_LMT_COUNT;
      if(kb_lmt_count[6] == 0)kb_lmt_count[6] = KB_LMT_COUNT/2;
    }
    //3 = RD
    if(output_count[6] && kb_lmt_count[6] == 0){
      output_count[6]--;
			P2_DR = 1023;
      kb_lmt_count[6] = KB_LMT_COUNT;
      if(kb_lmt_count[5] == 0)kb_lmt_count[5] = KB_LMT_COUNT/2;
    }


    if(with_input_balance){
      //交叉的部分
      //1P
      if(output_count[1] && kb_lmt_count[2] == 0){
        output_count[1]--;
				P1_DR = 1023;
        kb_lmt_count[2] = KB_LMT_COUNT;
        if(kb_lmt_count[1] == 0)kb_lmt_count[1] = KB_LMT_COUNT/2;
      }
      if(output_count[2] && kb_lmt_count[1] == 0){
        output_count[2]--;
				P1_DL = 1023;
        kb_lmt_count[1] = KB_LMT_COUNT;
        if(kb_lmt_count[2] == 0)kb_lmt_count[2] = KB_LMT_COUNT/2;
      }
      //2P
      if(output_count[5] && kb_lmt_count[6] == 0){
        output_count[5]--;
				P2_DR = 1023;
        kb_lmt_count[6] = KB_LMT_COUNT;
        if(kb_lmt_count[5] == 0)kb_lmt_count[5] = KB_LMT_COUNT/2;
      }
      if(output_count[6] && kb_lmt_count[5] == 0){
        output_count[6]--;
				P2_DL = 1023;
        kb_lmt_count[5] = KB_LMT_COUNT;
        if(kb_lmt_count[6] == 0)kb_lmt_count[6] = KB_LMT_COUNT/2;
      }
    }

    //输出
    GPIO_Output(0, kb_lmt_count[0] > KB_LMT_TRIG);
    GPIO_Output(1, kb_lmt_count[1] > KB_LMT_TRIG);
    GPIO_Output(2, kb_lmt_count[2] > KB_LMT_TRIG);
    GPIO_Output(3, kb_lmt_count[3] > KB_LMT_TRIG);
    GPIO_Output(4, kb_lmt_count[4] > KB_LMT_TRIG);
    GPIO_Output(5, kb_lmt_count[5] > KB_LMT_TRIG);
    GPIO_Output(6, kb_lmt_count[6] > KB_LMT_TRIG);
    GPIO_Output(7, kb_lmt_count[7] > KB_LMT_TRIG);
    
    //count down
    if(kb_lmt_count[0])kb_lmt_count[0]--;
    if(kb_lmt_count[1])kb_lmt_count[1]--;
    if(kb_lmt_count[2])kb_lmt_count[2]--;
    if(kb_lmt_count[3])kb_lmt_count[3]--;
    if(kb_lmt_count[4])kb_lmt_count[4]--;
    if(kb_lmt_count[5])kb_lmt_count[5]--;
    if(kb_lmt_count[6])kb_lmt_count[6]--;
    if(kb_lmt_count[7])kb_lmt_count[7]--;

		return;
	}
	
	for(uint8_t i = 0; i < CHANNEL_NUM; i ++){
		if(O_Buffer & (1 << i)){
			
			if(POWER_ON_EN){
        GPIO_Output(i, SystemSet.OutLoLength < O_CountDown[i]);
				if(flag[i] == 0){
					flag[i] = 1;
					switch(i){
						case 0:P1_KL = 1023;break;
						case 1:P1_DL = 1023;break;
						case 2:P1_DR = 1023;break;
						case 3:P1_KR = 1023;break;
						case 4:P2_KL = 1023;break;
						case 5:P2_DL = 1023;break;
						case 6:P2_DR = 1023;break;
						case 7:P2_KR = 1023;break;
					}
				}
				else flag[i] = 0xFF;
			}
			
			O_CountDown[i]--;
			
			if(O_CountDown[i] == 0){
				O_Buffer &= ~(1 << i);
				I_Buffer &= ~(1 << i);
			}
		}
		else{
			O_CountDown[i] = 0;
			flag[i] = 0;
		}
	}
}


//清除操作
void DoMute(uint8_t ID){
	I_Buffer &= ~(1 << ID);
	InputCount[ID] = 0;
	InputLevel_MAX[ID] = 0;
}

//操作输出
void DoOutput(uint8_t ID){
  
  UartDebug();
  
	//清除整组异端
  if(SystemSet.ADC_Mute_Side){
    
    if(ID > 3){
      DoMute(4);
      DoMute(5);
      DoMute(6);
      DoMute(7);
    }
    else{
      DoMute(0);
      DoMute(1);
      DoMute(2);
      DoMute(3);
    }
    
  }
  else{
    
    if(ID == 0 || ID == 3){
      DoMute(1);
      DoMute(2);
    }
    else if(ID == 1 || ID == 2){
      DoMute(0);
      DoMute(3);
    }
    else if(ID == 4 || ID == 7){
      DoMute(5);
      DoMute(6);
    }
    else if(ID == 5 || ID == 6){
      DoMute(4);
      DoMute(7);
    }
    else return;
    
    DoMute(ID);
    
  }
	
  //allow output
  O_Buffer |= 1 << ID;
  O_CountDown[ID] = SystemSet.OutHiLength + SystemSet.OutLoLength;
	//here need to make all channel mute
}


void REG_Output(uint8_t ID,uint16_t Level){
	
	//首次登记
	if(((I_Buffer>>ID)&1) == 0){
		I_Buffer |= 1<<ID;
		InputCount[ID] = 0;
	}
	
	//记录最大值
	if(Level > InputLevel_MAX[ID]){
		InputLevel_MAX[ID] = Level;
	}
	
}

//查找最大值，仅用于登记后
uint8_t CheckAdcMax(uint8_t ID, uint16_t* pValueList){
	
  uint16_t ADC_Value = pValueList[ID];
	
  if(SystemSet.ADC_Mute_Side){    
    
    switch(ID){
      //1P
      case 0:
        if(
          ADC_Value < pValueList[1]
         ||ADC_Value < pValueList[2]
         ||ADC_Value < pValueList[3]
          ){
          return 0;
        }
        else{
          return 1;
        }
        
      case 1:
        if(
          ADC_Value < pValueList[0]
         ||ADC_Value < pValueList[2]
         ||ADC_Value < pValueList[3]
          ){
          return 0;
        }
        else{
          return 1;
        }
        
      case 2:
        if(
          ADC_Value < pValueList[1]
         ||ADC_Value < pValueList[0]
         ||ADC_Value < pValueList[3]
          ){
          return 0;
        }
        else{
          return 1;
        }
        
      case 3:
        if(
          ADC_Value < pValueList[1]
         ||ADC_Value < pValueList[2]
         ||ADC_Value < pValueList[0]
          ){
          return 0;
        }
        else{
          return 1;
        }
        
        //2P
      case 4:
        if(
          ADC_Value < pValueList[5]
         ||ADC_Value < pValueList[6]
         ||ADC_Value < pValueList[7]
          ){
          return 0;
        }
        else{
          return 1;
        }
        
      case 5:
        if(
          ADC_Value < pValueList[4]
         ||ADC_Value < pValueList[6]
         ||ADC_Value < pValueList[7]
          ){
          return 0;
        }
        else{
          return 1;
        }
        
      case 6:
        if(
          ADC_Value < pValueList[5]
         ||ADC_Value < pValueList[4]
         ||ADC_Value < pValueList[7]
          ){
          return 0;
        }
        else{
          return 1;
        }
        
      case 7:
        if(
          ADC_Value < pValueList[5]
         ||ADC_Value < pValueList[6]
         ||ADC_Value < pValueList[4]
          ){
          return 0;
        }
        else{
          return 1;
        }
    }

  }
  
  else{    
    
    switch(ID){
      //1P
      case 0:
        if(
          ADC_Value < pValueList[1]
         ||ADC_Value < pValueList[2]
          ){
          return 0;
        }
        else{
          return 1;
        }
        
      case 1:
        if(
          ADC_Value < pValueList[0]
         ||ADC_Value < pValueList[3]
          ){
          return 0;
        }
        else{
          return 1;
        }
        
      case 2:
        if(
         ADC_Value < pValueList[0]
         ||ADC_Value < pValueList[3]
          ){
          return 0;
        }
        else{
          return 1;
        }
        
      case 3:
        if(
          ADC_Value < pValueList[1]
         ||ADC_Value < pValueList[2]
          ){
          return 0;
        }
        else{
          return 1;
        }
        
        //2P
      case 4:
        if(
          ADC_Value < pValueList[5]
         ||ADC_Value < pValueList[6]
          ){
          return 0;
        }
        else{
          return 1;
        }
        
      case 5:
        if(
          ADC_Value < pValueList[4]
         ||ADC_Value < pValueList[7]
          ){
          return 0;
        }
        else{
          return 1;
        }
        
      case 6:
        if(
         ADC_Value < pValueList[4]
         ||ADC_Value < pValueList[7]
          ){
          return 0;
        }
        else{
          return 1;
        }
        
      case 7:
        if(
          ADC_Value < pValueList[5]
         ||ADC_Value < pValueList[6]
          ){
          return 0;
        }
        else{
          return 1;
        }
    }

  }
	
	return 0;
  
}


/*
原理：收到自己被触发后，等待设置时间到
在时间段内有高于自己值的就屏蔽自己
*/

void CalPxMute_V2(uint8_t ID){
	
	//查找组内最大是否为本通道
	if(CheckAdcMax(ID, (uint16_t*)InputLevel_MAX)){
		DoOutput(ID);
	}
	else{
		DoMute(ID);
	}
	
}


#define AUTO_ZERO_LEN		2048

void AutoZero(void){
	static uint32_t ADC_ADD[CHANNEL_NUM] = {0}; 
	static uint16_t Count = 0;
	 
	if(I_Buffer){
		memset(ADC_ADD, 0, sizeof(ADC_ADD));
		Count = 0;
	}
	else{
		for(uint8_t i=0; i<CHANNEL_NUM; i++){
			ADC_ADD[i] += ADC_Now[i];
		}
		Count++;
		
		if(Count >= AUTO_ZERO_LEN){
			for(uint8_t i=0; i<CHANNEL_NUM; i++){
				ADC_Zero[i] = ADC_ADD[i] / Count;
			}
			memset(ADC_ADD, 0, sizeof(ADC_ADD));
			Count = 0;
      if(POWER_ON_EN == 0){
        memset((uint8_t*)InputLevel_MAX, 0, sizeof(InputLevel_MAX));
        POWER_ON_EN = 1;
      }
		}
	}
}
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
int main(void)
{
  /* USER CODE BEGIN 1 */
  uint16_t time = 0;
  /* USER CODE END 1 */

  /* MCU Configuration--------------------------------------------------------*/

  /* Reset of all peripherals, Initializes the Flash interface and the Systick. */
  HAL_Init();

  /* Configure the system clock */
  SystemClock_Config();

  /* Initialize all configured peripherals */
  MX_GPIO_Init();
  MX_IWDG_Init();
  MX_DMA_Init();
  MX_USART1_UART_Init();
  MX_TIM14_Init();
  MX_ADC1_Init();
  /* USER CODE BEGIN 2 */
  
  HAL_FLASH_Lock();
	
  HAL_Delay(10);
  
  ReadSet();
	
	SaveInit();
	
  if(SET_2){
		with_feq_limit = 1;
  }
	
	
	if(SET_3){
		with_input_balance = 1;
    OUT_BUFFER_LEN_D = 4;
	}
	
  HAL_IWDG_Refresh(&hiwdg);
  ON_Play();
	
  HAL_ADCEx_Calibration_Start(&hadc1);
  HAL_TIM_Base_Start_IT(&htim14);
  HAL_ADC_Start_DMA(&hadc1,(uint32_t *)ADC_Buffer,ADC_BUFFER_SIZE*ADC_CHANNEL_NUM);
  HAL_Delay(500);
	
	
	if(SET_4){
		MX_USART1_UART_Init246();//115200
    HAL_UART_Transmit_DMA(&huart1, (uint8_t*)"Power On In 246 Mode\r\n",sizeof("Power On In 246 Mode\r\n")-1);
    UsartStartRec();
		this_is_12ASIA = 1;
	}
	else if(SET_1){//38400
    HAL_UART_Transmit_DMA(&huart1, (uint8_t*)"Power On\r\n",sizeof("Power On\r\n")-1);
    UsartStartRec();
  }
	
	
	
  /* USER CODE END 2 */

  /* Infinite loop */
  /* USER CODE BEGIN WHILE */
  while (1)
  {
    
    HAL_IWDG_Refresh(&hiwdg);
		UsartTask();
    
    time++;
		if(time >= 1000){
      time = 0;
			checkSet();
		}
		if(time%10 == 0){
			ReadServiceKey();
		}
		
		if(SystemError){
			if(time % 20 == 0)
				HAL_GPIO_TogglePin(LED_STA_GPIO_Port,LED_STA_Pin);
		}
		else if(UnknowCMD){
			if(time < 500){
				if(time % 20 == 0)
					HAL_GPIO_TogglePin(LED_STA_GPIO_Port,LED_STA_Pin);
			}
			else
        HAL_GPIO_WritePin(LED_STA_GPIO_Port,LED_STA_Pin,GPIO_PIN_RESET);
		}
		else if(!JVS_OK && SET_4){
			if(time < 100){
				if(time % 20 == 0)
					HAL_GPIO_TogglePin(LED_STA_GPIO_Port,LED_STA_Pin);
			}
			else
        HAL_GPIO_WritePin(LED_STA_GPIO_Port,LED_STA_Pin,GPIO_PIN_RESET);
				
		}
		else if(POWER_ON_EN){
			if((time % 100) == 0)
				HAL_GPIO_TogglePin(LED_STA_GPIO_Port,LED_STA_Pin);
		}
		else{
        HAL_GPIO_WritePin(LED_STA_GPIO_Port,LED_STA_Pin,GPIO_PIN_SET);
		}
		
		if(JVS_OK)JVS_OK--;
    
    HAL_Delay(1);
    /* USER CODE END WHILE */

    /* USER CODE BEGIN 3 */
  }
  /* USER CODE END 3 */
}

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
/* USER CODE BEGIN 4 */



/**
  * @brief USART1 Initialization Function
  * @param None
  * @retval None
  */
static void MX_USART1_UART_Init246(void)
{

  huart1.Instance = USART1;
  huart1.Init.BaudRate = 115200;
  huart1.Init.WordLength = UART_WORDLENGTH_8B;
  huart1.Init.StopBits = UART_STOPBITS_1;
  huart1.Init.Parity = UART_PARITY_NONE;
  huart1.Init.Mode = UART_MODE_TX_RX;
  huart1.Init.HwFlowCtl = UART_HWCONTROL_NONE;
  huart1.Init.OverSampling = UART_OVERSAMPLING_16;
  huart1.Init.OneBitSampling = UART_ONE_BIT_SAMPLE_DISABLE;
  huart1.Init.ClockPrescaler = UART_PRESCALER_DIV1;
  huart1.AdvancedInit.AdvFeatureInit = UART_ADVFEATURE_NO_INIT;
  if (HAL_UART_Init(&huart1) != HAL_OK)
  {
    Error_Handler();
  }
  if (HAL_UARTEx_SetTxFifoThreshold(&huart1, UART_TXFIFO_THRESHOLD_1_8) != HAL_OK)
  {
    Error_Handler();
  }
  if (HAL_UARTEx_SetRxFifoThreshold(&huart1, UART_RXFIFO_THRESHOLD_1_8) != HAL_OK)
  {
    Error_Handler();
  }
  if (HAL_UARTEx_DisableFifoMode(&huart1) != HAL_OK)
  {
    Error_Handler();
  }
}



/**
  * @brief GPIO Initialization Function
  * @param None
  * @retval None
  */
#if (IS_S256 == 1)
static void MX_GPIO_Init(void)
{
  GPIO_InitTypeDef GPIO_InitStruct = {0};

  /* GPIO Ports Clock Enable */
  __HAL_RCC_GPIOA_CLK_ENABLE();
  __HAL_RCC_GPIOB_CLK_ENABLE();
  __HAL_RCC_GPIOC_CLK_ENABLE();
  __HAL_RCC_GPIOD_CLK_ENABLE();

  /*Configure GPIO pin Output Level */
  HAL_GPIO_WritePin(GPIOB, OUT1_Pin|OUT8_Pin|OUT7_Pin|OUT6_Pin
                          |OUT5_Pin|OUT4_Pin|OUT3_Pin|OUT2_Pin, GPIO_PIN_RESET);

  /*Configure GPIO pin Output Level */
  HAL_GPIO_WritePin(LED_STA_GPIO_Port, LED_STA_Pin, GPIO_PIN_RESET);

  /*Configure GPIO pin Output Level */
  HAL_GPIO_WritePin(DE_GPIO_Port, DE_Pin, GPIO_PIN_RESET);

  /*Configure GPIO pin Output Level */
  HAL_GPIO_WritePin(SENSE_GPIO_Port, SENSE_Pin, GPIO_PIN_RESET);

  /*Configure GPIO pins : OUT1_Pin OUT8_Pin OUT7_Pin OUT6_Pin
                           OUT5_Pin OUT4_Pin OUT3_Pin OUT2_Pin */
  GPIO_InitStruct.Pin = OUT1_Pin|OUT8_Pin|OUT7_Pin|OUT6_Pin
                          |OUT5_Pin|OUT4_Pin|OUT3_Pin|OUT2_Pin;
  GPIO_InitStruct.Mode = GPIO_MODE_OUTPUT_PP;
  GPIO_InitStruct.Pull = GPIO_NOPULL;
  GPIO_InitStruct.Speed = GPIO_SPEED_FREQ_LOW;
  HAL_GPIO_Init(GPIOB, &GPIO_InitStruct);

  /*Configure GPIO pins : SET1-4_Pin */
  GPIO_InitStruct.Pin = SET3_Pin|SET4_Pin|SET2_Pin|SET1_Pin;
  GPIO_InitStruct.Mode = GPIO_MODE_INPUT;
  GPIO_InitStruct.Pull = GPIO_PULLUP;
  HAL_GPIO_Init(GPIOD, &GPIO_InitStruct);

  /*Configure GPIO pin : LED_STA_Pin */
  GPIO_InitStruct.Pin = LED_STA_Pin;
  GPIO_InitStruct.Mode = GPIO_MODE_OUTPUT_PP;
  GPIO_InitStruct.Pull = GPIO_NOPULL;
  GPIO_InitStruct.Speed = GPIO_SPEED_FREQ_LOW;
  HAL_GPIO_Init(LED_STA_GPIO_Port, &GPIO_InitStruct);

  GPIO_InitStruct.Pin = DE_Pin;
  GPIO_InitStruct.Mode = GPIO_MODE_OUTPUT_PP;
  GPIO_InitStruct.Pull = GPIO_NOPULL;
  GPIO_InitStruct.Speed = GPIO_SPEED_FREQ_LOW;
  HAL_GPIO_Init(DE_GPIO_Port, &GPIO_InitStruct);

  GPIO_InitStruct.Pin = SENSE_Pin;
  GPIO_InitStruct.Mode = GPIO_MODE_OUTPUT_PP;
  GPIO_InitStruct.Pull = GPIO_NOPULL;
  GPIO_InitStruct.Speed = GPIO_SPEED_FREQ_LOW;
  HAL_GPIO_Init(SENSE_GPIO_Port, &GPIO_InitStruct);

  /*Configure GPIO pins : service_Pin */
  GPIO_InitStruct.Pin = KEY_TEST_Pin|KEY_SERVICE_Pin|KEY_ENTER_Pin|KEY_SEL_UP_Pin|KEY_COIN1_Pin;
  GPIO_InitStruct.Mode = GPIO_MODE_INPUT;
  GPIO_InitStruct.Pull = GPIO_NOPULL;
  HAL_GPIO_Init(GPIOB, &GPIO_InitStruct);

  GPIO_InitStruct.Pin = KEY_SEL_DOWN_Pin;
  GPIO_InitStruct.Mode = GPIO_MODE_INPUT;
  GPIO_InitStruct.Pull = GPIO_NOPULL;
  HAL_GPIO_Init(KEY_SEL_DOWN_GPIO_Port, &GPIO_InitStruct);

}
#else
static void MX_GPIO_Init(void)
{
  GPIO_InitTypeDef GPIO_InitStruct = {0};

  /* GPIO Ports Clock Enable */
  __HAL_RCC_GPIOB_CLK_ENABLE();
  __HAL_RCC_GPIOC_CLK_ENABLE();
  __HAL_RCC_GPIOA_CLK_ENABLE();

  /*Configure GPIO pin Output Level */
  HAL_GPIO_WritePin(GPIOB, OUT1_Pin|OUT8_Pin|OUT7_Pin|OUT6_Pin
                          |OUT5_Pin|OUT4_Pin|OUT3_Pin|OUT2_Pin, GPIO_PIN_RESET);

  /*Configure GPIO pin Output Level */
  HAL_GPIO_WritePin(LED_STA_GPIO_Port, LED_STA_Pin, GPIO_PIN_RESET);

  /*Configure GPIO pins : OUT1_Pin OUT8_Pin OUT7_Pin OUT6_Pin
                           OUT5_Pin OUT4_Pin OUT3_Pin OUT2_Pin */
  GPIO_InitStruct.Pin = OUT1_Pin|OUT8_Pin|OUT7_Pin|OUT6_Pin
                          |OUT5_Pin|OUT4_Pin|OUT3_Pin|OUT2_Pin;
  GPIO_InitStruct.Mode = GPIO_MODE_OUTPUT_PP;
  GPIO_InitStruct.Pull = GPIO_NOPULL;
  GPIO_InitStruct.Speed = GPIO_SPEED_FREQ_LOW;
  HAL_GPIO_Init(GPIOB, &GPIO_InitStruct);

  /*Configure GPIO pins : SET3_Pin SET4_Pin */
  GPIO_InitStruct.Pin = SET3_Pin|SET4_Pin;
  GPIO_InitStruct.Mode = GPIO_MODE_INPUT;
  GPIO_InitStruct.Pull = GPIO_PULLUP;
  HAL_GPIO_Init(GPIOC, &GPIO_InitStruct);

  /*Configure GPIO pins : SET2_Pin SET1_Pin */
  GPIO_InitStruct.Pin = SET2_Pin|SET1_Pin;
  GPIO_InitStruct.Mode = GPIO_MODE_INPUT;
  GPIO_InitStruct.Pull = GPIO_PULLUP;
  HAL_GPIO_Init(GPIOB, &GPIO_InitStruct);

  /*Configure GPIO pin : LED_STA_Pin */
  GPIO_InitStruct.Pin = LED_STA_Pin;
  GPIO_InitStruct.Mode = GPIO_MODE_OUTPUT_PP;
  GPIO_InitStruct.Pull = GPIO_NOPULL;
  GPIO_InitStruct.Speed = GPIO_SPEED_FREQ_LOW;
  HAL_GPIO_Init(LED_STA_GPIO_Port, &GPIO_InitStruct);

}
#endif
/* USER CODE END 4 */
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


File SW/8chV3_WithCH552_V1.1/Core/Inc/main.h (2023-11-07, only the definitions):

#define IS_S256		1
#define DE_Pin GPIO_PIN_8
#define DE_GPIO_Port GPIOA
#define SENSE_Pin GPIO_PIN_15
#define SENSE_GPIO_Port GPIOB
#define OUT1_Pin GPIO_PIN_14
#define OUT1_GPIO_Port GPIOB
#define OUT2_Pin GPIO_PIN_13
#define OUT2_GPIO_Port GPIOB
#define OUT3_Pin GPIO_PIN_12
#define OUT3_GPIO_Port GPIOB
#define OUT4_Pin GPIO_PIN_11
#define OUT4_GPIO_Port GPIOB
#define OUT5_Pin GPIO_PIN_10
#define OUT5_GPIO_Port GPIOB
#define OUT6_Pin GPIO_PIN_2
#define OUT6_GPIO_Port GPIOB
#define OUT7_Pin GPIO_PIN_1
#define OUT7_GPIO_Port GPIOB
#define OUT8_Pin GPIO_PIN_0
#define OUT8_GPIO_Port GPIOB
#define SET1_Pin GPIO_PIN_0
#define SET1_GPIO_Port GPIOD
#define SET2_Pin GPIO_PIN_1
#define SET2_GPIO_Port GPIOD
#define SET3_Pin GPIO_PIN_2
#define SET3_GPIO_Port GPIOD
#define SET4_Pin GPIO_PIN_3
#define SET4_GPIO_Port GPIOD
#define IN1_Pin GPIO_PIN_0
#define IN1_GPIO_Port GPIOA
#define IN2_Pin GPIO_PIN_1
#define IN2_GPIO_Port GPIOA
#define IN3_Pin GPIO_PIN_2
#define IN3_GPIO_Port GPIOA
#define IN4_Pin GPIO_PIN_3
#define IN4_GPIO_Port GPIOA
#define IN5_Pin GPIO_PIN_4
#define IN5_GPIO_Port GPIOA
#define IN6_Pin GPIO_PIN_5
#define IN6_GPIO_Port GPIOA
#define IN7_Pin GPIO_PIN_6
#define IN7_GPIO_Port GPIOA
#define IN8_Pin GPIO_PIN_7
#define IN8_GPIO_Port GPIOA
#define LED_STA_Pin GPIO_PIN_15
#define LED_STA_GPIO_Port GPIOA
#define SWDIO_Pin GPIO_PIN_13
#define SWDIO_GPIO_Port GPIOA
#define SWCLK_Pin GPIO_PIN_14
#define SWCLK_GPIO_Port GPIOA
#define KEY_TEST_Pin	GPIO_PIN_9
#define KEY_TEST_GPIO_Port	GPIOB
#define KEY_SERVICE_Pin	GPIO_PIN_8
#define KEY_SERVICE_GPIO_Port	GPIOB
#define KEY_ENTER_Pin	GPIO_PIN_7
#define KEY_ENTER_GPIO_Port	GPIOB
#define KEY_SEL_UP_Pin	GPIO_PIN_6
#define KEY_SEL_UP_GPIO_Port	GPIOB
#define KEY_COIN1_Pin	GPIO_PIN_5
#define KEY_COIN1_GPIO_Port	GPIOB
#define KEY_SEL_DOWN_Pin	GPIO_PIN_13
#define KEY_SEL_DOWN_GPIO_Port GPIOC
#define OUT1_Pin GPIO_PIN_9
#define OUT1_GPIO_Port GPIOB
#define SET3_Pin GPIO_PIN_14
#define SET3_GPIO_Port GPIOC
#define SET4_Pin GPIO_PIN_15
#define SET4_GPIO_Port GPIOC
#define IN1_Pin GPIO_PIN_0
#define IN1_GPIO_Port GPIOA
#define IN2_Pin GPIO_PIN_1
#define IN2_GPIO_Port GPIOA
#define IN3_Pin GPIO_PIN_2
#define IN3_GPIO_Port GPIOA
#define IN4_Pin GPIO_PIN_3
#define IN4_GPIO_Port GPIOA
#define IN5_Pin GPIO_PIN_4
#define IN5_GPIO_Port GPIOA
#define IN6_Pin GPIO_PIN_5
#define IN6_GPIO_Port GPIOA
#define IN7_Pin GPIO_PIN_6
#define IN7_GPIO_Port GPIOA
#define IN8_Pin GPIO_PIN_7
#define IN8_GPIO_Port GPIOA
#define SET2_Pin GPIO_PIN_0
#define SET2_GPIO_Port GPIOB
#define SET1_Pin GPIO_PIN_1
#define SET1_GPIO_Port GPIOB
#define OUT8_Pin GPIO_PIN_2
#define OUT8_GPIO_Port GPIOB
#define LED_STA_Pin GPIO_PIN_8
#define LED_STA_GPIO_Port GPIOA
#define SWDIO_Pin GPIO_PIN_13
#define SWDIO_GPIO_Port GPIOA
#define SWCLK_Pin GPIO_PIN_14
#define SWCLK_GPIO_Port GPIOA
#define OUT7_Pin GPIO_PIN_3
#define OUT7_GPIO_Port GPIOB
#define OUT6_Pin GPIO_PIN_4
#define OUT6_GPIO_Port GPIOB
#define OUT5_Pin GPIO_PIN_5
#define OUT5_GPIO_Port GPIOB
#define OUT4_Pin GPIO_PIN_6
#define OUT4_GPIO_Port GPIOB
#define OUT3_Pin GPIO_PIN_7
#define OUT3_GPIO_Port GPIOB
#define OUT2_Pin GPIO_PIN_8
#define OUT2_GPIO_Port GPIOB
#define SYNC 0xE0
#define ESCAPE 0xD0
#define BROADCAST 0xFF
#define BUS_MASTER 0x00
#define DEVICE_ADDR_START 0x01
#define STATUS_SUCCESS 0x01
#define STATUS_UNSUPPORTED 0x02      // an unsupported command was sent
#define STATUS_CHECKSUM_FAILURE 0x03 // the checksum on the command packet did not match a computed checksum
#define STATUS_OVERFLOW 0x04         // an overflow occurred while processing the command
#define REPORT_SUCCESS 0x01          // all went well
#define REPORT_PARAMETER_ERROR1 0x02 // TODO: work out difference between this one and the next
#define REPORT_PARAMETER_ERROR2 0x03
#define REPORT_BUSY 0x04 // some attached hardware was busy, causing the request to fail
#define CMD_RESET 0xF0            // reset bus
#define CMD_RESET_ARG 0xD9        // fixed argument to reset command
#define CMD_ASSIGN_ADDR 0xF1      // assign address to slave
#define CMD_SET_COMMS_MODE 0xF2   // switch communications mode for devices that support it, for compatibility
#define CMD_REQUEST_ID 0x10       // requests an ID string from a device
#define CMD_COMMAND_VERSION 0x11  // gets command format version as two BCD digits packed in a byte
#define CMD_JVS_VERSION 0x12      // gets JVS version as two BCD digits packed in a byte
#define CMD_COMMS_VERSION 0x13    // gets communications version as two BCD digits packed in a byte
#define CMD_CAPABILITIES 0x14     // gets a special capability structure from the device
#define CMD_CONVEY_ID 0x15        // convey ID of main board to device
#define CMD_READ_SWITCHES 0x20    // read switch inputs
#define CMD_READ_COINS 0x21       // read coin inputs
#define CMD_READ_ANALOGS 0x22     // read analog inputs
#define CMD_READ_ROTARY 0x23      // read rotary encoder inputs
#define CMD_READ_KEYPAD 0x24      // read keypad inputs
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

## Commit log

2023-10-30 new
    new
    [IO256.kicad_sch, OPA.kicad_sch, SIF PCB.kicad_sch]
2023-11-07 add software
    [IO256.kicad_pcb, IO256.kicad_sch, OPA.kicad_sch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]

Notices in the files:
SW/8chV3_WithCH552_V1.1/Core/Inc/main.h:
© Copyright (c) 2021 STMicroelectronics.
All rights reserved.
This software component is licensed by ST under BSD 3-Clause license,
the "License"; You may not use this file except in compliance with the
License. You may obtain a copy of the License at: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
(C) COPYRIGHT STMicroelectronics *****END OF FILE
